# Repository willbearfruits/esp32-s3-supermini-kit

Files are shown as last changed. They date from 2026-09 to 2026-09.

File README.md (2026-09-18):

# ESP32-S3 SuperMini Audio Kit

An open-source, solderless, 3D-printable handheld built around the ESP32-S3
SuperMini. Microphone in, stereo line-out, a small OLED, an encoder,
a joystick, and optional speaker amplification, distance sensing and an IMU.
Headphones require a separate headphone amplifier.

This repo will grow into everything needed to build one or sell one: firmware,
carrier PCB, enclosure, bill of materials, and assembly instructions.

**Status: five firmware applications, a printable case, a purchasing list, and
an illustrated prototype assembly guide.** The carrier PCB remains unfinished;
the current build uses prepared headers and a wired harness.

## Build your first kit

[**Start the beginner-friendly assembly guide**](docs/assembly/README.md) ·
[**Printable PDF (16 pages)**](output/pdf/esp32-s3-supermini-assembly-guide.pdf) ·
[Browser checklist](docs/assembly/index.html) ·
[SVG and PNG diagrams](docs/assembly/assets/)

Make a little noise: the SuperMini handheld

Build it one small win at a time: flash the test app, light the screen, add the
mic and line-out, check the controls, fit the case, and make your first beat.
The guide includes wiring tables, checkpoints, case hardware, and troubleshooting.
Download the repository and open `docs/assembly/index.html` for the offline
interactive checklist. Exact module revisions and enclosure fit need checking
before assembly; the guide documents the prototype, not a physically validated kit.

## Firmware applications

The firmware builds as one of:

| App | `tools/app.sh` | What it is |
|-----|---|---|
| JAM | `jam` (default) | Step sequencer and sampler for the boxed unit: six channels on a scale-locked grid, slices you can scratch, roll and chaos for breakcore, mixer with insert effects, eight pattern banks, a song page, autosave. Encoder and joystick only. |
| Looper | `looper` | Hum, beatbox or whistle and get a track: up to 8 tracks on a fixed grid, scenes and an arrangement, stereo mix, autosave, WAV/MIDI export over a USB drive mode. |
| Faust showcase | `faust` | Mic through seven [Faust](https://faust.grame.fr) programs (zita reverb, pitch shift, wah, amp sim, flanger, compressor, a pitch-following synth), each with presets. |
| Hardware test | `test` | Mic to DAC with a wiring diagnosis on the screen and serial log, a boot-time test tone, delay/reverb/beat repeat. Flash this first on a new build. |
| Instrument | `instrument` | The older eight-mode voice instrument. |

## Parts

| Part | Role | Bus |
|---|---|-----|
| ESP32-S3 SuperMini | brain, native USB | |
| INMP441 | MEMS microphone | I2S (RX) |
| PCM5102A | line-out DAC (headphones need an amp) | I2S (TX) |
| MAX98357A | 3 W speaker amp | I2S (TX) |
| 0.96" SSD1306 OLED | display | I2C |
| Rotary encoder with button | input | GPIO |
| Analog joystick with button | input | ADC1 + GPIO |
| VL53L0X (optional) | time-of-flight distance | I2C |
| MPU6050 (optional) | gyro + accelerometer | I2C |

All three audio chips share one I2S port. See [docs/pinmap.md](docs/pinmap.md)
for the wiring and why that works.

The current [minimal purchasing list](parts/minimal-kit.md) is **your carrier PCB
plus seven parts**: ESP32-S3, purple PCM5102A board, joystick board with pins,
bare encoder, round six-pin I2S mic, 0.96-inch I2C OLED and MPU6050 board.
Available as [PDF](parts/minimal-kit.pdf) and [CSV](parts/minimal-kit.csv).
The [earlier expanded research](parts/purchasing-kit.md) keeps the additional
options and CAD references. Shipping and exact module dimensions remain unverified.

## Repo layout

```
firmware/     ESP-IDF project (C, a little C++ for the Faust glue)
firmware/faust/  Faust sources; tools/faustgen.sh turns them into C++ under firmware/main/faust/
tools/        app.sh (switch application), faustgen.sh
docs/         pin map, wiring diagram, acoustics notes
enclosure/    parametric OpenSCAD case, renders and STLs (0.8 mm nozzle, heat-set inserts)
3d/           earlier concept bodies (slab, ocarina, cup)
parts/        purchasing lists, datasheets and drawings
images/       photos and rendered screens
hardware/     later: KiCad carrier PCB
```

## Build one

The illustrated [assembly guide](docs/assembly/README.md), also as a
[16-page PDF](output/pdf/esp32-s3-supermini-assembly-guide.pdf), takes a first-time
builder from parts to a first beat: power, flashing the test image, adding
one module at a time, the bench check, the case, then JAM.

## Flash a release

No toolchain needed: each [release](https://github.com/willbearfruits/esp32-s3-supermini-kit/releases)
has one `.bin` per application that flashes at offset 0 with esptool or in the
browser. See [docs/flashing.md](docs/flashing.md).

## Build the firmware

Requires [ESP-IDF](https://docs.espressif.com/projects/esp-idf/en/stable/esp32s3/get-started/index.html)
v5.5 or newer with the `esp32s3` target installed.

```sh
. ~/esp/esp-idf/export.sh        # or wherever your IDF lives
cd firmware
idf.py set-target esp32s3
idf.py build
idf.py flash monitor
```

The SuperMini's USB-C is wired to the S3's native USB, so it usually flashes
without pressing anything. If it does not show up, hold BOOT, tap RESET,
release BOOT, then flash again.

Pick the application with `tools/app.sh jam` (or `looper`, `faust`, `test`,
`instrument`), which edits `sdkconfig` and rebuilds. Tunables live under
`idf.py menuconfig` -> `Kit firmware`: application, mic gain, sample rate,
tempo, encoder steps, OLED rotation, whether the speaker amp is always on.

Wiring note: the INMP441's L/R pin may go to GND or VDD, the firmware finds
which I2S slot carries the mic. The joystick's VRy goes to GPIO1 and VRx to
GPIO2 (see [docs/pinmap.md](docs/pinmap.md)).

## Using JAM

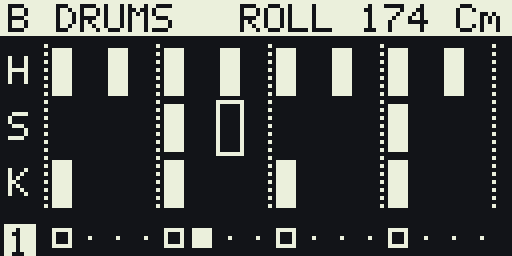
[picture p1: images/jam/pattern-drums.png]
drums
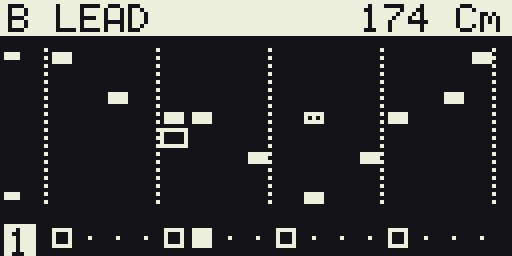
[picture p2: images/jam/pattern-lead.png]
lead
 
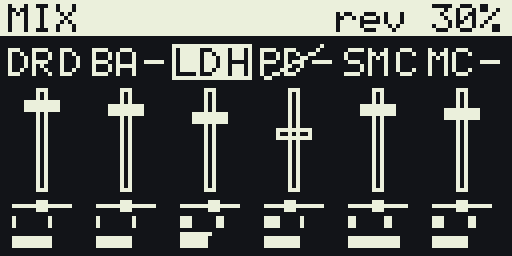
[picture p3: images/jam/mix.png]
mixer
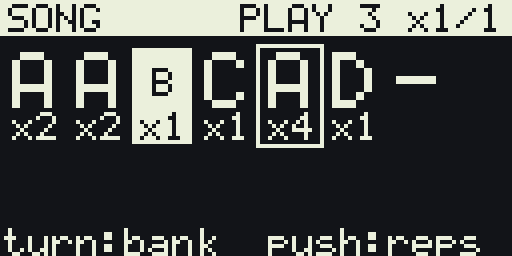
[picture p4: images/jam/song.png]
song
 

Four pages, cycled by holding the encoder for half a second: **PATTERN**,
**MIX**, **SONG**, **SETUP**. Push the encoder in and turn it to change
channel (DRUMS, BASS, LEAD, PAD, SAMPLE, MIC). Hold it 3 s to clear the
channel.

**PATTERN** is the step grid of the channel, two bars of 16 steps. Turn the
encoder or flick the joystick to move the cursor, tap the encoder to toggle
the cell. Drums have kick, snare and hat lanes. Melodic channels have one
row per degree of the scale chosen in SETUP plus the octave, so notes cannot
leave the key. PAD rows are chord degrees. SAMPLE plays the recording pitched
by row, or in SLICE mode one of eight slices per row, where a lit cell tapped
again plays in reverse. MIC is the live mic, only audible while selected;
tap the encoder there to record up to two seconds into the sampler.

Click the joystick for **perform** mode. On DRUMS the stick rolls the last
hit, from 1/8 to 1/64 by tilt, louder or softer along the other axis. On
SAMPLE it first scratches the recording like a record, click again and it
rolls with a pitch ramp. On BASS and LEAD it opens the filter and bends, on
PAD and MIC it pushes the reverb and delay sends. Hold the encoder and flick
up or down to switch pattern bank, A to H, instantly.

**MIX** shows a fader per channel with pan, reverb and delay sends, an insert
effect (drive, crush, chorus, phaser, wobble, tremolo) and its amount.
**SONG** chains banks with repeat counts, tap to play from the cursor.
**SETUP** has tempo up to 250, root and scale (major, minor, dorian,
mixolydian, harmonic minor, two pentatonics, blues), a drum pattern to load
into the grid, swing, CHAOS (the chance that a step rolls, drops, swaps or
reverses), the drum kit and synth presets, and COPY and CLEAR ALL.

Everything is saved two seconds after the last edit and comes back at
power-up.

## Using the looper

One encoder, one joystick, optional tilt sensor and distance sensor. Same
grammar everywhere:

| Gesture | Does |
|---|---|
| turn | next / previous track (in the menu: move, or change a value) |
| push | record a take on this track; push again to cancel |
| hold 0.6 s | menu (in the menu: back) |
| hold 3 s | clear all patterns |
| joystick tilt | expression: brightness and pitch bend |
| joystick click | mute this track |
| joystick flick up / down | next / previous scene, switched at the loop start |
| joystick flick left / right | track |
| body tilt | vibrato (roll) and brightness (pitch) |
| hand over the distance sensor | space (reverb send) |

A take is exactly one loop. Push, the metronome counts in one bar (or waits
for the loop to come round once something is playing), the take records for
one loop and stops by itself. Takes overdub by default; Take -> Replace next
or Undo change that. Drums are beatboxed (kick / snare / hat by the sound's
band energies), bass, keys and lead are hummed or whistled and snapped to
the grid and the key, the vocal track is a hard-tuned voice recorded as
audio. The key locks on the first melodic take, or set it in Song -> Key.

Menu sections: **Take** (undo, replace, copy A here, clear), **Track**
(sound, volume, pan, reverb, delay, low cut, tone, mute, solo, add / delete
track), **Scene** (scene, song mode, arrangement), **Song** (tempo, bars,
key, count-in, metronome, quantise, swing, humanise, kit, mic gain, gate),
**Master** (pump, drive, tone), **Files** (export, save / load slot, new,
USB drive).

USB drive mode (Files -> USB drive, or hold the encoder at power-up) shows
the storage partition to the PC and makes the board a MIDI device. Drop
`kick.wav`, `snare.wav`, `hat.wav` into `kits/user/` for your own drum kit;
exports land in `export/` as one WAV per track, a stereo `mix.wav`,
`song.mid` and `song.txt`. Hold the button to return. Flashing needs the
board out of USB mode (or BOOT held at power-up).

The serial log prints the current track, scene, key, the voice tracker's
level and confidence, the DSP load with a per-section breakdown, and which
inputs were detected.

## Faust

Effects and the JAM synth voice are written in Faust under `firmware/faust/`.
After editing a `.dsp`, run `tools/faustgen.sh` (needs the `faust` compiler
on PATH) to regenerate the C++ classes under `firmware/main/faust/`, which
are committed so a normal build never needs Faust. Avoid table-based
oscillators on this chip, each costs 256 KB of internal RAM.

## Roadmap

- [x] Pin map
- [x] I2S loopback (mic -> DACs)
- [x] OLED, encoder and joystick input
- [x] ToF and IMU readouts (looper)
- [x] 3D-printed enclosure ([enclosure/](enclosure/), first revision)
- [x] Purchasing list ([parts/minimal-kit.md](parts/minimal-kit.md))
- [ ] Carrier PCB (KiCad) with sockets for every module
- [x] Illustrated prototype assembly guide ([web](docs/assembly/README.md), [PDF](output/pdf/esp32-s3-supermini-assembly-guide.pdf), SVG/PNG artwork)

## License

Firmware and documentation: [MIT](LICENSE). Hardware files, when they land,
will be CERN-OHL-P.

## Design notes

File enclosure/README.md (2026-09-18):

# 3D OpenSCAD Enclosure for ESP32-S3 Audio Kit (Shortlist Edition)

For the full build, use the [beginner assembly guide](../docs/assembly/README.md)
or [16-page printable PDF](../output/pdf/esp32-s3-supermini-assembly-guide.pdf).
It covers bench testing, wiring, dry-fit checks, and enclosure assembly. The
dimensions below describe the CAD; verify them against your actual boards,
headers, plugs, inserts, and screws before printing or fastening.

A custom, ergonomic, 3D-printable handheld enclosure designed specifically for the **six parts of the Minimal Audio Kit shortlist** (plus internal mounting for the MPU6050 IMU), optimized for **0.8 mm nozzle printing** and **brass heat-set threaded inserts**.

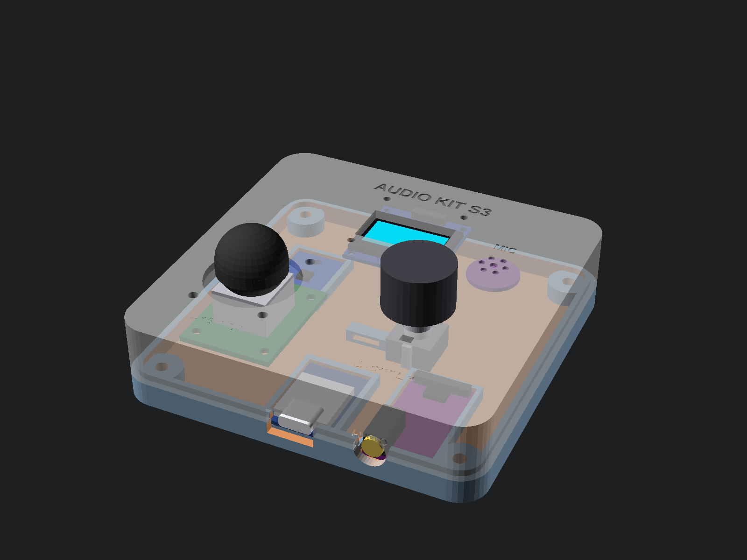
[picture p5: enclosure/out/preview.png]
Enclosure Preview


---

## 1. Overall Dimensions & Specifications

- **Outer Dimensions:** `100.0 mm` (Width, X) × `98.0 mm` (Length, Y) × `24.0 mm` (Height, Z)
- **Top Shell Height:** `17.0 mm`
- **Bottom Lid Height:** `7.0 mm` (parting line at Z = 7.0 mm)
- **Corner Radius:** `8.0 mm` rounded ergonomic corners
- **Wall Thickness:** `2.4 mm` (exactly 3 perimeters of 0.8 mm nozzle extrusion)
- **Floor & Ceiling Thickness:** `2.4 mm` (solid 6 layers at 0.40 mm)

---

## 2. The Six Shortlist Parts & Placement

| # | Part | Role & Specification | Enclosure Integration |
|---|---|---|---|
| **1** | **ESP32-S3 SuperMini** | ESP32-S3FH4R2, 4MB Flash / 2MB PSRAM, USB-C | Lower-center lid cradle (`X = 41.0 to 59.0 mm`); USB-C port cutout on bottom edge with cable shroud relief. |
| **2** | **PCM5102A I2S DAC** | **32 × 17 mm** purple board, 3.5mm jack on a short end, offset to one side. Size, jack edge, jack offset and which wall it exits are in the Customizer group *PCM5102A DAC board* in `enclosure.scad`. | Lid cradle along the right wall (`X = 68.5 to 85.5 mm`, `Y = 2.9 to 34.9 mm`), jack **exits through the front wall** beside the USB-C port. |
| **3** | **Analog Joystick** | KY-023-style module with fitted pins and thumb cap | Lower-left quadrant (`X = 22.5, Y = 32.5 mm`); 26.5 mm diameter dome aperture; 4 M2 internal screw bosses with **>3.7 mm clearance to ESP32 cradle** and **>5.2 mm to ESP32 PCB** (zero overlap). |
| **4** | **Rotary Encoder** | Bare EC11 with push switch and vertical shaft | Lower-right quadrant (`X = 70.0, Y = 32.5 mm`); 7.5 mm through-hole for M7 threaded bushing, anti-rotation locator notch, recessed dial bezel. |
| **5** | **I2S Microphone** | **Round 14.5 mm 6-pin board** (INMP441) | **Mounted on top layer next to the OLED display** (`X = 78.0, Y = 65.0 mm`); acoustic 7-hole rosette grille with conical chamfers, internal gasket seat, and circular retention collar (zero overlap with OLED). |
| **6** | **0.96-inch OLED** | SSD1306, 128×64, 4-pin I2C | Upper front center (`X = 36.35 to 63.65 mm, Y = 58.0 mm`); recessed beveled viewing window; 4 M2 mounting standoffs. |
| *(7)* | *MPU6050 IMU* | *GY-521 6-DoF accelerometer & gyro (motion sensor)* | *Internal retention cradle on lid floor; rigidly anchored to chassis for tilt sensing.* |

---

## 3. 0.8 mm Nozzle & Heat-Set Insert Engineering

### A. 0.8 mm Nozzle Geometries
Printing with a 0.8 mm nozzle requires walls, perimeters, and tolerances to be integer multiples of the extrusion line width:
- **Wall Thickness:** `2.4 mm` (exactly 3 solid perimeters of 0.8 mm).
- **Floor & Roof Thickness:** `2.4 mm` (6 solid layers at 0.40 mm layer height).
- **Alignment Lip (Tongue & Groove):** `1.6 mm` (exactly 2 solid perimeters).
- **Sliding Clearance (`tol`):** `0.40 mm` (accommodates 0.8 mm corner bulging for a smooth sliding fit).
- **Acoustic Grille Openings:** 7-hole rosette (center: 2.2 mm, surround: 1.8 mm) allows the 0.8 mm nozzle to lay down crisp circular paths without stringing or merging.
- **Labels:** Bold embossed/debossed typography with stroke widths exceeding 0.8 mm for clean legibility.

### B. Heavy-Duty Brass Heat-Set Threaded Inserts
Rather than self-tapping into weak plastic, the top shell contains thick, heavy-duty structural corner bosses designed for **heat-set brass threaded inserts**:
- **Default configuration:** `insert_type = "M3"`:
  - **Boss Outer Diameter:** `Ø11.5 mm` (providing **~3.5 mm solid wall thickness / ~4.5 continuous perimeters** around the brass insert).
  - **Insert Hole Diameter:** `Ø4.5 mm` (tailored for standard M3 heat-set inserts with OD ~4.6 mm).
  - **Insert Depth:** `5.8 mm` (for standard 4.0 mm – 5.7 mm insert lengths).
  - **Conical Lead-In Chamfer:** 0.8 mm deep 45° lead-in chamfer ensures the brass insert rests perfectly vertical and self-centers before touching with the soldering iron tip.
- **Selectable in OpenSCAD:** Supports `"M2"`, `"M2.5"`, or `"M3"` with matching screw clearances and counterbores.
- **Lid Screw Holes:** `Ø3.6 mm` pass-through clearance with `Ø7.2 mm × 3.2 mm` deep counterbores so M3 socket/pan head screws sit flush with the bottom surface.

---

## 4. Exploded Assembly

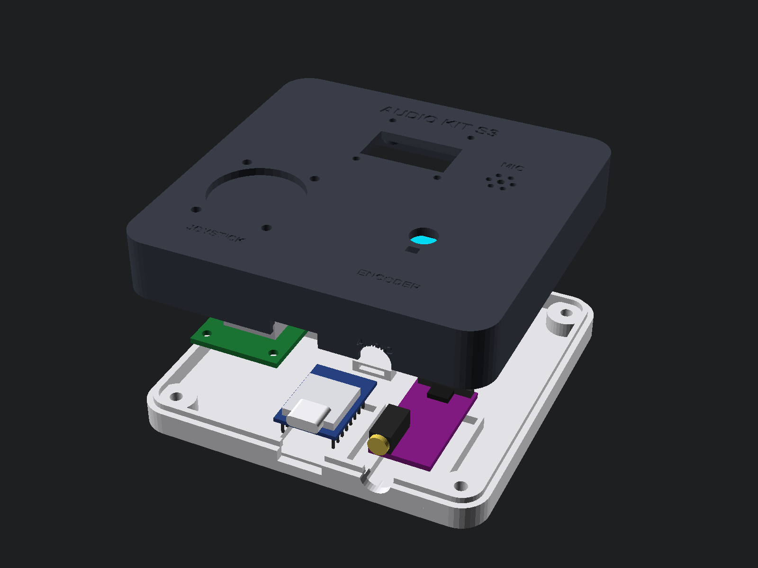
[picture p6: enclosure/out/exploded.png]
Exploded Assembly


1. **Top Shell Prep & Assembly:**
   - Press four **M3 brass heat-set inserts** into the corner bosses using a soldering iron (set to ~230–250°C for PLA/PETG).
   - Fasten the **SSD1306 OLED** to the upper window bosses with four M2 screws.
   - Place a small foam/silicone gasket ring into the microphone seat on the top layer, press the **Round INMP441 mic** into its circular collar, and route leads.
   - Insert the **EC11 Encoder** through its panel hole and tighten the M7 nut on the outside; press the knob onto the 6mm D-shaft.
   - Mount the **KY-023 Joystick** onto its four standoff bosses using four M2 screws.
2. **Bottom Lid Assembly:**
   - Slide the **ESP32-S3 SuperMini** into its cradle (USB-C facing outward on the bottom edge).
   - Slide the **PCM5102A DAC** into its cradle (3.5mm stereo jack facing outward through the front wall cutout beside the USB-C).
   - Press the **MPU6050 IMU** into its internal retention cradle.
   - Wire connections according to [`docs/pinmap.md`](../docs/pinmap.md) and secure wires through the cable anchor loop.
3. **Closing Case:**
   - Place the bottom lid onto the top shell (the 1.6 mm interlocking lip aligns both halves smoothly).
   - Fasten with four **M3 × 10 mm (or 12 mm)** socket-head or pan-head machine screws from the underside (counterbored flush).

---

## 5. 3D Printing Guidelines

Both parts are designed for **100% support-free printing**:

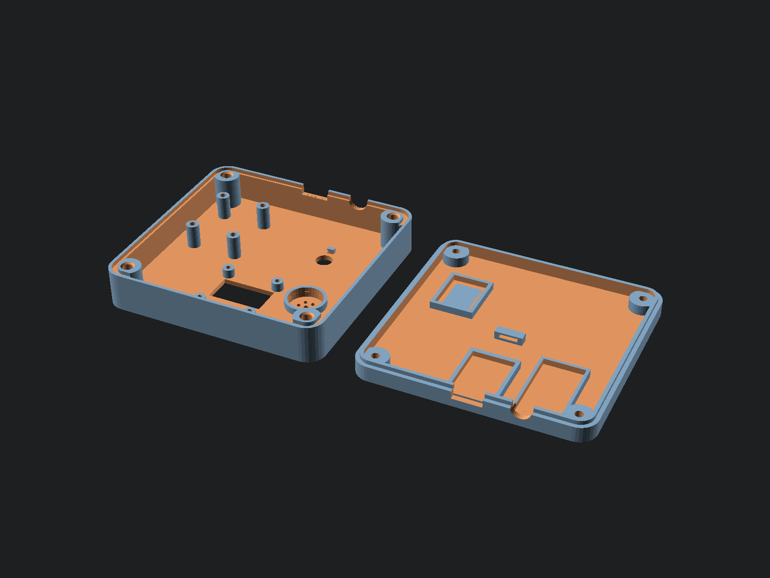
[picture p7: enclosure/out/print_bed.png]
Print Bed Layout


- **Print Bed Setup:** Open [`print_bed.scad`](print_bed.scad) or load [`out/print_bed.stl`](out/print_bed.stl) directly into your slicer (OrcaSlicer, PrusaSlicer, Bambu Studio, Cura).
- **Top Shell Orientation:** Printed **top-face down** flat on the build plate (Z=0). Heat-set insert bosses and walls grow vertically upward.
- **Bottom Lid Orientation:** Printed **bottom-face down** flat on the build plate (Z=0).
- **Nozzle Diameter:** 0.8 mm
- **Recommended Material:** PLA, PLA+, or PETG.
- **Layer Height:** 0.32 mm – 0.40 mm (fast printing, ~1 hour total print time!).
- **Perimeters / Walls:** 3 perimeters (gives 100% solid 2.4 mm walls).
- **Top / Bottom Solid Layers:** 4 to 6 layers.
- **Infill:** 20% to 30% (Gyroid or Grid).
- **Supports:** **NONE** (0% support needed).

---

## 6. Hardware Bill of Materials

| Item | Quantity | Purpose |
|---|---|---|
| M3 brass heat-set inserts (OD ~4.6 mm, L ~4–5.7 mm) | 4 | Corner fasteners in Top Shell (or M2.5 / M2) |
| M3 × 10 mm (or 12 mm) machine screws | 4 | Case closure through Bottom Lid (counterbored flush) |
| M2 × 4 mm screws | 4 | OLED display mounting |
| M2 × 6 mm screws | 4 | KY-023 Joystick module mounting |
| EC11 M7 nut & washer | 1 | Rotary encoder panel fixing |
| Foam/silicone gasket ring (~10–14 mm OD) | 1 | Microphone acoustic isolation |
| Rubber bumper feet (~8 mm diameter) | 4 | Optional non-slip feet for lid recesses |

---

## 7. Files & Customization

- [`enclosure.scad`](enclosure.scad): Main parametric OpenSCAD design script.
- [`parts.scad`](parts.scad): 3D component models and negative cutouts library.
- [`print_bed.scad`](print_bed.scad): Build plate layout file for single-plate slicing.
- [`render.sh`](render.sh): Shell script to render PNG previews and export STLs.
- [`out/`](out/):
  - [`print_bed.stl`](out/print_bed.stl): Ready-to-slice 2-in-1 build plate STL (Top Shell + Bottom Lid).
  - [`shell.stl`](out/shell.stl): Ready-to-slice Top Shell STL.
  - [`lid.stl`](out/lid.stl): Ready-to-slice Bottom Lid STL.
  - `preview.png`: Transparent assembled preview.
  - `exploded.png`: Exploded assembly diagram.
  - `assembled.png`: Solid external case view.
  - `print_bed.png`: Both parts arranged flat for 3D printing.

### CLI Rendering Commands

```bash
# Render all views and STLs
./render.sh

# Or open interactively in OpenSCAD
openscad enclosure.scad
```

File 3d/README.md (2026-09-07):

# 3D-printable bodies

Parametric OpenSCAD (tested with 2021.01). Three options that share one
parts library:

| File | Option | Idea |
|---|---|---|
| `handheld.scad` | A, slab | Game-Boy-shaped box: OLED, encoder, joystick on top, sealed speaker sub-box, mic on the top edge, battery under the lid. |
| `ocarina.scad` | B, ocarina | A Helmholtz chamber sized for a chosen lowest note, fipple and four finger holes; the mic listens inside the chamber. Electronics in a bay underneath. |
| `cup.scad` | C, cup on a wand | Mic at the bottom of a cup you press to your mouth, controls along the handle. Maximum isolation for beatboxing. |

`parts.scad` holds every module's size. **All of them are typical values,
not measurements.** Measure your boards and fix the numbers before printing.
`acoustics.scad` has the resonance formulas, explained in
[docs/acoustics.md](../docs/acoustics.md).

```sh
./render.sh            # previews in out/*.png and STLs in out/*.stl
openscad handheld.scad # or open interactively
```

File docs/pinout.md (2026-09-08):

# Pinout

| Pin | Function | Goes to | Notes |
|----:|---|---|---|
| | | | |

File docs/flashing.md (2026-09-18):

# Flashing without ESP-IDF

Every [release](https://github.com/willbearfruits/esp32-s3-supermini-kit/releases)
ships one image per application, each a single file that flashes at offset 0:

| File | Application |
|---|---|
| `kit-jam.bin` | JAM, the step sequencer and sampler (what the boxed kit runs) |
| `kit-looper.bin` | the voice looper |
| `kit-test.bin` | hardware test: mic to DAC with a wiring diagnosis on the screen |

## With esptool (Linux, macOS, Windows)

```sh
pip install esptool
esptool.py --chip esp32s3 --port /dev/ttyACM0 write_flash 0x0 kit-jam.bin
```

Use the port your system gives the board: `/dev/ttyACM0` on Linux,
`/dev/cu.usbmodem*` on macOS, `COM3` or similar on Windows. Leave `--port`
out and esptool tries them all.

## In the browser

Open [esptool-js](https://espressif.github.io/esptool-js/) in Chrome or Edge,
connect, choose the file with flash address `0x0`, program. No install.

## If the board does not show up

The SuperMini uses the S3's native USB, so it normally enumerates by itself.
If it does not, or the flash fails partway: hold BOOT, tap RESET, release
BOOT, then flash again. The board reboots into the new firmware afterwards.
A cable that only carries power is the usual cause of a board that never
appears.

## After flashing

JAM saves its patterns on the board; a first boot writes defaults. The
hardware test image is the one to flash when something is wired wrong: it
names the likely missing wire on the screen and in the serial log at
115200 baud.

## Building the images yourself

`tools/release.sh` with ESP-IDF sourced builds all three and merges each with
its bootloader and partition table into `release/<version>/`.

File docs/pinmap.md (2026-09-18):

# Pin map

Board: **ESP32-S3 SuperMini** (ESP32-S3FH4R2, 4 MB flash, 2 MB PSRAM, native USB).
All GPIO logic is 3.3 V. Module supply voltages differ: the documented
regulator-equipped purple DAC uses 5 V at VIN, while the microphone and
joystick use 3V3. Verify each breakout's supply rating and power path; the
optional speaker amp needs a supply with enough current, not an assumed load
on the SuperMini's small 3V3 regulator.

New to the build? Follow the [illustrated assembly guide](assembly/README.md)
or its [printable PDF](../output/pdf/esp32-s3-supermini-assembly-guide.pdf).
Its staged diagrams use signal labels, not physical header positions.

The canonical copy of this table lives in `firmware/main/pins.h`. If you change one, change the other.

| GPIO | Name | Goes to | Notes |
| -: | - | - | - |
| 1 | JOY\_Y | Joystick VRy | ADC1 |
| 2 | JOY\_X | Joystick VRx | ADC1 |
| 3 | JOY\_SW | Joystick SW | active low, internal pull-up |
| 4 | ENC\_A | Encoder CLK / A |  |
| 5 | ENC\_B | Encoder DT / B |  |
| 6 | ENC\_SW | Encoder SW | active low, internal pull-up |
| 7 | I2S\_BCLK | INMP441 **SCK**, PCM5102A **BCK**, MAX98357A **BCLK** | shared bit clock |
| 8 | I2S\_WS | INMP441 **WS**, PCM5102A **LCK**, MAX98357A **LRC** | shared word select |
| 9 | I2S\_DOUT | PCM5102A **DIN**, MAX98357A **DIN** | ESP32 -\> DACs |
| 10 | I2S\_DIN | INMP441 **SD** | mic -\> ESP32 |
| 11 | AMP\_SD | MAX98357A **SD** | low = amp off |
| 12 | I2C\_SDA | OLED, ToF, IMU SDA |  |
| 13 | I2C\_SCL | OLED, ToF, IMU SCL |  |
| 21 | SPARE | free | ToF XSHUT or IMU INT later |

Pins deliberately left alone: 0 (BOOT button), 19/20 (USB), 43/44 (UART0), 48 (onboard RGB LED), 45/46 (strapping).

Why the joystick sits on GPIO1 and GPIO2: those are ADC1 channels. ADC2 stops working while WiFi is active on the ESP32-S3, so never put analog inputs there.

## Why one I2S port is enough

The ESP32-S3 has two I2S ports. We use only port 0, in full duplex:

- The two DACs are receivers. Receivers can share a bus freely, so both get the same BCLK, WS and data line and play the same stream.

- The mic is a transmitter, so it needs its own data line into the ESP32, but it can still share BCLK and WS with the DACs.

- The only rule is that everyone runs at the same sample rate and slot width. We use 32-bit slots, stereo, Philips format. All three chips accept that.

- None of the three chips needs MCLK.

Total cost: 4 GPIOs for the entire audio path.

Trade-off: both DACs always play the same audio. If you ever want different audio on speaker vs line-out, move one DAC to I2S port 1 (3 more pins).

## Module wiring

### INMP441 microphone (round board, 6 pins)

| INMP441 | Connect to |
| - | - |
| VDD | 3V3 |
| GND | GND |
| SD | GPIO 10 |
| SCK | GPIO 7 |
| WS | GPIO 8 |
| L/R | GND (data lands in the left slot; the firmware also accepts it tied to VDD, right slot) |

### PCM5102A DAC (purple board, line-out)

The output is line level. Use powered speakers, an audio-interface line input,
or a separate headphone amplifier; ordinary headphones need amplification.
Confirm the regulator, VIN rating, and strap functions for your exact board.

| PCM5102A | Connect to |
| - | - |
| VIN | 5V (the board has its own 3.3 V regulator; on 3V3 it sags to ~3.0 V and the analog side suffers) |
| GND | GND |
| LCK | GPIO 8 |
| DIN | GPIO 9 |
| BCK | GPIO 7 |
| SCK | GND (most boards already do this on the PCB) |

Check the four solder bridges on the back. They must be:

| Bridge | Pin | Set to |
| - | - | - |
| H1L | FLT | L |
| H2L | DEMP | L |
| H3L | XSMT | H |
| H4L | FMT | L |

Boards often ship with one or more of these open. An open XSMT means the DAC stays muted forever. This is the one component in the kit that may need a soldering iron, so for a solderless kit either buy pre-bridged boards or move these straps onto the carrier PCB.

### MAX98357A amplifier (speaker out)

| MAX98357A | Connect to |
| - | - |
| VIN | Verified regulated supply within the module's rating, with enough current for the speaker load; keep GPIO logic at 3.3 V |
| GND | GND |
| SD | GPIO 11 |
| GAIN | leave floating (9 dB) |
| DIN | GPIO 9 |
| BCLK | GPIO 7 |
| LRC | GPIO 8 |
| + / - | speaker, 4 or 8 ohm |

Driving SD low shuts the amp down; channel selection with SD high depends on
the breakout's SD_MODE network. The firmware starts with it low and, by default,
enables it while the GPIO6 encoder switch is held. `CONFIG_KIT_AMP_ALWAYS_ON`
keeps it enabled. Neither speaker output terminal may be connected to GND.
See the assembly guide's optional-extension section for power and mounting limits.

### I2C devices

All on GPIO 12 (SDA) and GPIO 13 (SCL). Addresses do not clash:

| Device | Address |
| - | - |
| SSD1306 0.96" OLED | 0x3C |
| VL53L0X ToF (the current driver does not implement VL53L1X) | 0x29 |
| MPU6050 IMU | 0x68 |

Most breakout boards include pull-ups. If none of yours do, add 4.7 k to 3V3 on SDA and SCL.

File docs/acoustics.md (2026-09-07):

# Acoustics for the enclosure

What the box can and cannot do for a MEMS microphone, with the formulas the
OpenSCAD files use. Speed of sound c = 343 m/s.

## The one formula that matters: Helmholtz

A cavity of volume V with an opening of area A and neck length L resonates at

    f = c / (2 pi) * sqrt( A / (V * L_eff) ),   L_eff = L + 1.7 r

where r is the opening radius and the 1.7 r term is the end correction. This
is the ocarina, the cup, a ported speaker box and a bottle, all at once.

Turned around: the volume you need for a target frequency is

    V = A / ( L_eff * (2 pi f / c)^2 )

### Consequence 1: no handheld cavity reaches kick range

For 100 Hz with a 20 mm opening and a 20 mm neck you need 2.5 litres. For
200 Hz still 630 cm3. Anything that fits in a hand (50-150 cm3) resonates
between 400 and 900 Hz, the vowel range. So the enclosure cannot boost the
"b" of a beatbox kick. Kick versus hat separation stays electronic, which the
firmware already does with band energies.

### Consequence 2: it reaches whistle range easily

The same 81 cm3 chamber with a 4 x 12 mm window resonates at A4 = 440 Hz. That
is an ocarina, and it is the strongest acoustic idea for this kit: a fipple
turns breath into a loud, pure tone with a stable fundamental. The YIN
tracker locks onto it instantly, with none of the jitter a voice gives, and it
is 20 dB above room noise so the gate has nothing to think about. Voice and
beatbox still work on the other pages, the ocarina is just a very good pitch
controller for bass, chords and lead.

Finger holes add their own A / L_eff to the sum inside the square root, so
opening a hole raises the pitch. `ocarina.scad` solves the hole diameters for
a list of target notes; expect to be within a semitone and then tune by
enlarging (sharper) or taping (flatter), as every ocarina maker does.

## Tubes

A tube closed at one end resonates at odd multiples of c / 4L. A 15 cm tube
gives 572, 1715, 2858 Hz: a talkbox-like colour on the voice, nothing at the
fundamental. Fun, but it does not help tracking.

## What a cup does

The INMP441 is omnidirectional, so it has no proximity effect: there is no
bass boost from getting close. What a cup around the mic gives is isolation.
Lips on the rim, the voice arrives at the mic 15-20 dB above the room and the
speaker, which is exactly the "mic is too sensitive" complaint solved in
plastic. Sealed by the lips it becomes a Helmholtz resonator around 700 Hz
(printed by `cup.scad`), mild vowel colour, harmless for pitch.

## The microphone port

The INMP441 hears through a hole in its PCB. Mount the board face-down over a
1.5 mm port in the shell with a thin foam or rubber gasket so sound only
enters through the port. Keep the port short: a long narrow port plus the
tiny cavity in front of the membrane makes its own resonance, and below about
2 mm length and 1.5 mm diameter that sits above 10 kHz where it does not
matter. A slotted grille 5 mm in front of the port, with a thin foam disc,
is the pop filter.

## The speaker

A 40 mm 3 W driver in a sealed box needs volume to keep any bass: 26 cm3 (the
slab as drawn) is on the small side, 60-100 cm3 is comfortable. A port would
have to be large to tune below 200 Hz (see consequence 1), so stay sealed and
let the firmware make the bass. What matters more is feedback: the speaker
box must be its own sealed volume, separate from the mic side, with foam in
between, or the mic-to-speaker loop howls with the amp on.

## Gyroscope

Not acoustic, but worth deciding now: the MPU6050 goes near the centre of the
body, screwed rigidly to the shell, axes aligned with the body. Tilt then
maps cleanly to expression (vibrato, filter, pitch bend) without calibration
tricks.

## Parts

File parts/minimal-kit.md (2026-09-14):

# Minimal audio kit — 7 parts

**Your carrier PCB + seven purchased parts per kit.** For ten kits: buy ten of each, preferably one 10-piece lot. Scope confirmed 9 September 2026: **joystick on a board with pins; encoder bare**.

| # | Part | Required version | AliExpress candidate |
|---|---|---|---|
| 1 | ESP32-S3 SuperMini | ESP32-S3FH4R2, 4 MB flash / 2 MB PSRAM, USB-C | [1–10 pcs](https://www.aliexpress.com/item/1005012191736844.html) |
| 2 | PCM5102A I2S DAC | **Purple board**, with audio jack | [1–10 pcs](https://www.aliexpress.com/item/1005010369195534.html) |
| 3 | Analog joystick | **KY-023-style board with fitted pins and cap**; X, Y and push button | [1/5/10 pcs](https://www.aliexpress.com/item/1005008298413198.html) |
| 4 | Rotary encoder | **Bare EC11 with push button**, vertical shaft | [10 pcs](https://www.aliexpress.com/item/1005005239756119.html) |
| 5 | I2S microphone | **Small round six-pin board**; INMP441 assumed from this project | [1/5/10 pcs](https://www.aliexpress.com/item/1005009006830769.html) |
| 6 | 0.96-inch OLED | SSD1306, 128×64, **I2C SDA/SCL**, four pins | [10 pcs](https://www.aliexpress.com/item/1005008169257099.html) |
| 7 | Gyroscope / accelerometer | **MPU6050 GY-521 board**, I2C | [10 pcs](https://www.aliexpress.com/item/1005011896641210.html) |

**Ordering status:** these are listing leads. Select the 10-piece variant where available. Free shipping/Choice, fitted headers, the purple DAC version, round microphone version and exact board drawings remain **unverified**. Country/postcode and readable seller details are still needed. The ten-kit batch is **70 purchased parts + 10 of your carrier PCBs**.

**Documentation and CAD:** [PCM5102A datasheet](https://www.ti.com/lit/ds/symlink/pcm5102a.pdf) · [INMP441 datasheet](https://invensense.tdk.com/wp-content/uploads/2015/02/INMP441.pdf) · [MPU6050 datasheet](https://product.tdk.com/system/files/dam/doc/product/sensor/mortion-inertial/imu/data_sheet/mpu-6000-datasheet1.pdf) · [KY-023 module manual/dimensions reference](https://www.joy-it.net/en/products/COM-KY023JM) · [SSD1306 OLED module dimensions reference](https://www.joy-it.net/files/files/Produkte/SBC-OLED01/SBC-OLED01_Datasheet_2022-01-06.pdf). Reference-board dimensions must be matched to the actual supplier's boards. Exact DipTrace libraries remain unverified; existing drawings and CAD leads are in the [detailed research](purchasing-kit.md).

**Carrier design:** use the actual module header layouts and bare encoder footprint. Keep joystick outputs and I2C pull-ups at 3.3 V. The purple DAC's input power and configuration straps depend on its revision. Its output is line level; if headphone drive is wanted, account for that in the carrier design. [TI DAC specification](https://www.ti.com/lit/ds/symlink/pcm5102a.pdf).

Listing-title evidence: [ESP32](https://sv.pricearchive.org/aliexpress.com/item/1005012191736844) · [DAC](https://www.pricearchive.org/aliexpress.com/item/1005010369195534) · [joystick](https://ms.pricearchive.org/aliexpress.com/item/1005008298413198) · [encoder](https://sv.pricearchive.org/aliexpress.com/item/1005005239756119) · [mic](https://vi.pricearchive.org/aliexpress.com/item/1005009006830769) · [OLED](https://ro.pricearchive.org/aliexpress.com/item/1005008169257099) · [IMU](https://www.pricearchive.org/aliexpress.com/item/1005011896641210). These indexed records do not verify shipping or the selected variant.

[Editable seven-part CSV](minimal-kit.csv) · [Earlier expanded research](purchasing-kit.md)

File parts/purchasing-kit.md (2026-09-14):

# ESP32-S3 audio kit — purchasing shortlist

**Earlier expanded research.** The current build uses [seven purchased parts plus your carrier PCB](minimal-kit.md), with a joystick board with pins and a bare encoder. Use that minimal list for the current kit; the broader options below are retained as research references.

Research date: **9 September 2026**. Working quantity: **10 complete kits**. Encoder and joystick are **bare through-hole components, without breakout boards**; the other electronics are modules. Destination and this quantity assumption await confirmation.

**Purchase status: shipping and exact-product drawing checks are pending. No listing is yet confirmed to meet all your requirements.** This document contains real listing leads, manufacturer documentation and the remaining parts needed to finish the build. It is not an AliExpress cart, and no orders have been placed.

AliExpress product pages could not be read successfully through the research tool. The listing links below were identified through indexed Pricearchive/Alitools records; their titles establish candidate parts and advertised pack sizes only. Stock, selected variants, seller identity, authenticity, Choice eligibility, prices and delivery charges remain unverified. The adjacent “listing evidence” links preserve that distinction.

## Your buying requirements

- Prefer one **10-piece lot** per part; larger lots are acceptable. A listing headed “1–10 pieces” needs the **10-piece variant**, with cart quantity **1**. Ten single pieces or five pairs are exceptions, not automatically equivalent to the requested lot.
- Require **zero shipping charge to your delivery address** for the selected lot. I interpret “AliExpress special” as **Choice**, pending confirmation. Alibaba describes Choice shipping as conditional on market and purchase thresholds; its general description does not establish today's terms for your address. Check both the product and final basket. [Alibaba's Choice explanation](https://www.alibabagroup.com/en-US/document-1696296090350911488).
- Require a manual/datasheet with **dimensions and mounting information for the actual item supplied**. For modules this means the PCB, header positions, holes, connector heights and protrusions. A chip's package drawing alone does not qualify a module.
- Prefer DipTrace symbols/footprints and matching STEP models. A similar-looking component or another manufacturer's breakout is only a reference.

## Main components: one of each per kit

Every row below has a target of **10 physical pieces**. Optional sensors are included in that target so all ten kits can have motion and distance control. **Shipping/Choice: unverified for every row. Live lot price: unverified for every row.**

| ID | Part and exact selection | Advertised lot and AliExpress link | Documentation / remaining gap |
|---|---|---|---|
| K01 | **ESP32-S3 SuperMini, ESP32-S3FH4R2**, 4 MB flash, 2 MB PSRAM, native USB-C | **1–10 pcs**, select 10: [listing](https://www.aliexpress.com/item/1005012191736844.html) · [listing evidence](https://sv.pricearchive.org/aliexpress.com/item/1005012191736844) | Exact SuperMini PCB drawing not verified. Firmware requires this S3/PSRAM configuration; a C3 SuperMini is unsuitable. Documented Waveshare alternative below. |
| K02 | **INMP441 I2S microphone breakout**, with L/R pin accessible | **1/5/10 pcs**, select 10: [listing](https://www.aliexpress.com/item/1005009006830769.html) · [listing evidence](https://vi.pricearchive.org/aliexpress.com/item/1005009006830769) | [TDK chip datasheet](https://invensense.tdk.com/wp-content/uploads/2015/02/INMP441.pdf). Exact board dimensions, acoustic-port position and pin layout still needed. Do not select a different microphone from a mixed listing without checking it. |
| K03 | **PCM5102A stereo I2S DAC module**, preferably with fitted 3.5 mm line-output jack | **1–10 pcs**, select 10: [listing](https://www.aliexpress.com/item/1005010369195534.html) · [listing evidence](https://www.pricearchive.org/aliexpress.com/item/1005010369195534) | [TI datasheet](https://www.ti.com/lit/ds/symlink/pcm5102a.pdf) · [saved PDF](research-2026-09-09/PCM5102A-chip-datasheet.pdf). Exact PCB/jack drawing, regulator and mute straps still needed. This is line output; see headphone amplifier below. |
| K04 | **MAX98357A mono I2S speaker amplifier module**; require the **A** version | **10 pcs / 1 pc**, select 10: [listing](https://www.aliexpress.com/item/1005009759175798.html) · [listing evidence](https://www.pricearchive.org/aliexpress.com/item/1005009759175798) | [Analog Devices datasheet/CAD](https://www.analog.com/en/products/MAX98357A.html). Listing title omits the suffix: confirm A, board dimensions, SD/GAIN circuitry and terminal block. A uses I2S; B uses left-justified audio. |
| K05 | **0.96-inch SSD1306 OLED**, 128×64, **4-pin I2C**, white | **10 pcs / lot**: [listing](https://www.aliexpress.com/item/1005008169257099.html) · [listing evidence](https://ro.pricearchive.org/aliexpress.com/item/1005008169257099) | Exact PCB, glass, active-area and mounting-hole drawing needed. Confirm 0x3C address, 3.3 V operation and header order. Do not substitute SH1106, 128×32 or SPI. |
| K06 | **Bare EC11 rotary encoder with push switch**, 3 encoder pins + 2 switch pins, vertical shaft | **10 pcs**, choose shaft style/length: [listing](https://www.aliexpress.com/item/1005005239756119.html) · [listing evidence](https://sv.pricearchive.org/aliexpress.com/item/1005005239756119) | **Hold for seller drawing.** Generic EC11 does not identify one footprint. Need body, lug spacing, shaft length/diameter, bushing, detents and pulses. Exact documented ALPS alternative below. No KY-040 board. |
| K07 | **Bare ALPS RKJXV1224005 joystick**, two 10 kΩ linear pots, spring return, center push | **10–100 pcs**, select 10: [listing](https://www.aliexpress.com/item/1005011995304794.html) · [listing evidence](https://ro.pricearchive.org/aliexpress.com/item/1005011995304794) | [ALPS exact-part documentation](https://tech.alpsalpine.com/e/products/detail/RKJXV1224005/). **17.8 × 21.3 × 11.2 mm**; dimension, mounting and lever drawings saved below. Best exact-model 10-piece lead found. Seller identity/authenticity and supplied model still need confirmation. Cap inclusion unknown. No KY-023 board. |
| K08 | **MPU6050 / GY-521 breakout**, gyro + accelerometer | **10 pcs**: [listing](https://www.aliexpress.com/item/1005011896641210.html) · [listing evidence](https://www.pricearchive.org/aliexpress.com/item/1005011896641210) | [TDK chip datasheet](https://product.tdk.com/system/files/dam/doc/product/sensor/mortion-inertial/imu/data_sheet/mpu-6000-datasheet1.pdf). Exact GY-521 PCB drawing needed. Require 3.3 V-compatible power/I2C and AD0 low for 0x68. Optional in firmware, included here. |
| K09 | **VL53L0X I2C distance-sensor breakout** | **10 pcs / 1 pc**, select specifically VL53L0X and 10: [listing](https://www.aliexpress.com/item/1005010777247203.html) · [listing evidence](https://uk.pricearchive.org/aliexpress.com/item/1005010777247203) | [ST datasheet](https://www.st.com/resource/en/datasheet/vl53l0x.pdf). Mixed-family listing: exact sensor, direct I2C interface, board drawing and voltage compatibility need confirmation. VL53L1X and serial-output TOF boards are not drop-in replacements for this firmware. Optional, included here. |
| K10 | **40 mm round speaker, 4 Ω, 3 W nominal**, with leads if possible | **1/2/10 pcs**, select 10 and 40 mm: [listing](https://www.aliexpress.com/item/1005009533204416.html) · [listing evidence](https://www.pricearchive.org/aliexpress.com/item/1005009533204416) | **Hold for full drawing.** Diameter alone is insufficient: magnet depth, rim, terminals and mounting are needed. The enclosure's 5.5 mm speaker depth is an unmeasured placeholder. |
| K11 | **Stereo headphone amplifier**, if headphones are required; TDA1308 board is a candidate | **10 pcs / 1 pc**, select 10: [listing](https://www.aliexpress.com/item/1005009791615188.html) · [listing evidence](https://ms.pricearchive.org/aliexpress.com/item/1005009791615188) | **Design/sourcing hold.** [NXP TDA1308 documentation](https://www.nxp.com/products/TDA1308). Require schematic, dimensions, stereo headphone load rating, gain and output coupling. Listing calls it a microphone preamp, so its suitability is unconfirmed. TDA1308 is discontinued; do not commit a new production design on this lead alone. |

No total cost is provided: indexed starting prices often correspond to one piece or a different variant. The CSV leaves actual selected-lot price and shipping fields blank for verified quotes.

## The bare controls and their drawings

**Joystick K07:** ALPS documents the exact RKJXV1224005, including its center switch. It is marked **not recommended for new designs**. For a longer-lived design, consider the current **RKJXV122400R**, documented as **18.2 × 21.7 × 11.2 mm**. The two outlines differ; do not use one drawing for the other. A matching 10-piece AliExpress lot for the R version was not confirmed. [4005 specifications](https://tech.alpsalpine.com/e/products/detail/RKJXV1224005/) · [400R specifications](https://tech.alpsalpine.com/e/products/detail/RKJXV122400R/).

| Saved manufacturer drawing | What it establishes |
|---|---|
| [RKJXV1224005 dimensions](research-2026-09-09/ALPS-RKJXV1224005-dimensions.gif) | Body, terminals and overall geometry |
| [RKJXV1224005 mounting holes](research-2026-09-09/ALPS-RKJXV1224005-mounting.gif) | PCB hole layout; observe the manufacturer's mounting-side view |
| [RKJXV1224005 lever](research-2026-09-09/ALPS-RKJXV1224005-lever.gif) | Cap-interface geometry |
| [EC11E15244G1 dimensions](research-2026-09-09/ALPS-EC11E15244G1-dimensions.gif) | Exact ALPS encoder outline |
| [EC11E15244G1 mounting holes](research-2026-09-09/ALPS-EC11E15244G1-mounting.gif) | Exact ALPS encoder PCB hole layout |

**Encoder alternative:** [ALPS EC11E15244G1](https://tech.alpsalpine.com/e/products/detail/EC11E15244G1/) has a 20 mm flat shaft, 30 detents, 15 pulses and a push switch. An [AliExpress listing naming this exact model](https://www.aliexpress.com/item/1005008895804725.html) advertises **2 pieces** ([listing evidence](https://www.pricearchive.org/aliexpress.com/item/1005008895804725)). Five packs would yield ten encoders, but **does not meet your 10-piece-lot requirement**. It is an alternative only if you accept that exception; shipping is also unverified. The saved ALPS drawings do **not** qualify the generic K06 lot.

Bare controls need soldering to a carrier PCB, including their mechanical support tabs. The assembled carrier can then form a plug-in kit. They will not plug straight into the five-pin breakout sockets shown in generic Arduino wiring diagrams.

## DipTrace libraries and 3D models

**No exact native DipTrace symbol/footprint set was verified for the AliExpress lots.** These are the useful resources actually found:

| Part | Resource | Status and applicability |
|---|---|---|
| ALPS EC11E15244G1 | [ALPS product page](https://tech.alpsalpine.com/e/products/detail/EC11E15244G1/) | Exact dimension/mounting drawings saved. Page offers 3D CAD under member access; model not downloaded or checked. |
| ALPS RKJXV122400R | [SnapMagic symbol/footprint/3D page](https://www.snapeda.com/parts/RKJXV122400R/ALPS/view-part/) | Page advertises CAD resources but previews/pinout were unavailable. No import or geometry validation performed; not a verified 4005 model. ALPS also offers a member CAD route for the R part. |
| Waveshare ESP32-S3-Zero | [Official hardware resources](https://docs.waveshare.com/ESP32-S3-Zero/Resources-And-Documents) · [saved STEP](research-2026-09-09/Waveshare-ESP32-S3-Zero-v2.stp) · [saved dimension drawing](research-2026-09-09/Waveshare-ESP32-S3-Zero-dimensions.jpg) | **Manufacturer STEP downloaded**, file header checked. Drawing is 18 × 23.5 mm, 2.54 mm side pitch, 15.24 mm row spacing. These files belong to Waveshare's board; no generic SuperMini match is established. |
| Adafruit MAX98357A, product 3006 | [Module drawings and Eagle files](https://learn.adafruit.com/adafruit-max98357-i2s-class-d-mono-amp/downloads) · [STEP repository](https://github.com/adafruit/Adafruit_CAD_Parts/tree/main/3006%20MAX98357) | Manufacturer module CAD available. Applies to Adafruit's board, not automatically K04's clone. |
| PCM5102A chip | [TI product/CAD page](https://www.ti.com/product/PCM5102A) | Ultra Librarian link for IC symbol, package footprint and 3D. A carrier for K03 needs a module footprint instead. |
| MAX98357A chip | [Analog Devices product/CAD page](https://www.analog.com/en/products/MAX98357A.html) | Ultra Librarian/SamacSys resources by package. Select the exact package only for a future board using the bare IC. |
| Other candidate boards | Exact module libraries not verified | Draw the module outline, header pads, mounting holes and keepouts from its supplier drawing after the SKU is fixed. |

DipTrace supports importing other CAD formats. SamacSys explains that its former DipTrace downloads used PADS files and that these now reside in its PADS folder. Treat this as an **import route**, not native DipTrace availability. Follow the installed version's documentation, import footprint and component together, then check pin numbers, hole sizes and model alignment. [SamacSys explanation](https://www.samacsys.com/supporting-diptrace/) · [DipTrace import documentation](https://www.diptrace.com/support/tutorials/help_html/).

## Other parts needed to finish ten kits

These quantities are procurement allowances where the carrier has not yet been designed. Search links are explicitly **searches**, not checked product listings. Shipping and drawings remain open for these items too.

| Item | Quantity for ten kits | Buying specification / link |
|---|---|---|
| Encoder knobs | **10**, one 10-pack | [10-piece listing](https://www.aliexpress.com/item/33003636792.html) · [listing evidence](https://alitools.io/en/showcase/10pcs-6mm-shaft-hole-amplifier-knob-for-encoder-potentiometer-knobs-33003636792). Match the selected 6 mm shaft profile, bore depth and push clearance; obtain outside dimensions. |
| Joystick caps | **10**, if not supplied | Match the exact ALPS lever drawing. [AliExpress search](https://www.aliexpress.com/w/wholesale-10pcs-joystick-thumbstick-cap.html). Do not assume PS4/PS5/Xbox caps are interchangeable. |
| Male header strips | Budget **20 × 1×40**, 2.54 mm | Two 10-packs; deduct headers included with modules. [Search](https://www.aliexpress.com/w/wholesale-10pcs-1x40-2.54-male-header.html). Final cut lengths depend on selected boards. |
| Female socket strips | Budget **20 × 1×40**, 2.54 mm | Two [10-piece lots](https://www.aliexpress.com/item/1005013054690432.html) · [listing evidence](https://www.pricearchive.org/aliexpress.com/item/1005013054690432). Confirm socket height/drawing. Cutting ordinary sockets may sacrifice a position; pin budget is provisional. |
| USB data cables | **10** | USB-A to USB-C with USB 2.0 data conductors; choose a stated length such as 0.5 m. [Search](https://www.aliexpress.com/w/wholesale-10pcs-usb-a-usb-c-data-cable.html). Charge-only cables cannot flash or export files. |
| Power supply | **10 if each kit needs one** | Regulated 5 V supply; initial engineering allowance 2 A per kit, subject to power-path design and measured load. [Search](https://www.aliexpress.com/w/wholesale-10pcs-5v-2a-usb-power-supply.html). Plug type and destination remain open. |
| Speaker connectors/leads | **10 mating pairs** if detachable | Choose one exact connector, e.g. genuine JST-PH 2 mm, with a supplier drawing and adequate current rating. [Search](https://www.aliexpress.com/w/wholesale-10sets-jst-ph-2.0-2pin-wire.html). Terminal blocks supplied on the amp can remove this requirement. |
| Headphone sockets | **10 if absent from chosen headphone amp** | 3.5 mm stereo TRS socket. [Search](https://www.aliexpress.com/w/wholesale-10pcs-3.5mm-stereo-pcb-jack.html). Select exact part and pinout before drawing PCB; the DAC's existing socket remains line-out unless rerouted. |
| Internal wire/harnesses | **10 sets**, final lengths pending | Short signal wiring plus suitably sized power/speaker wiring. [Search](https://www.aliexpress.com/w/wholesale-10pcs-dupont-jumper-wire-set.html). Bare controls mount on the carrier; jumpers alone do not mount them. |
| Carrier PCBs | **10 assembled carriers** | **Not ready to order.** The repository has no finished carrier layout/manufacturing files. Bare control footprints, sockets, power distribution and mounting must be designed first. Final carrier resistors/capacitors/connectors require its schematic BOM. |
| I2C pull-up resistors | Allow **20 × 4.7 kΩ**; buy a 100-pack | Only populate if needed after checking module pull-ups. [Search](https://www.aliexpress.com/w/wholesale-100pcs-4.7k-resistor.html). Package is a carrier-design decision. |
| Supply/ADC/filter passives | **TBD by carrier schematic** | Reserve decoupling and bulk capacitance, and control filtering as required. Do not order an invented final value/package list before the power and carrier circuits exist. |
| Enclosures/lids | **10 printed pairs** | Existing [3D designs](../3d/README.md) require the final part dimensions. Select handheld/ocarina/cup before manufacturing. |
| Screws and mounting hardware | At least **40 lid screws** for handheld; allow a 100-pack | Handheld CAD has four lid screws per kit; module and carrier fixings are additional. M2-family hardware is the current intent, but length/type depend on final bosses. [Search](https://www.aliexpress.com/w/wholesale-100pcs-m2-self-tapping-screws.html). |
| Microphone/speaker gasket material | **10 cut sets** | Cut foam/gasket pieces to the actual mic port and speaker rim. Enclosure-dependent; protect the microphone opening from blockage. |

No external microSD card, SD module or crystal is specified for the current module build: firmware stores songs in the ESP32's onboard flash, and the modules provide their chip support circuits.

## Battery operation needs a completed power design

The enclosure contains placeholders for a 1S battery and TP4056 board, but the repository does not define a finished battery power path. The complete portable version additionally needs **10 protected 1S cells**, **10 suitable charging/power-path assemblies**, **10 5 V converters if not integrated**, **10 switches**, and matching battery harnesses. Battery size/capacity, charge current and connector polarity must be fixed together.

A TP4056 module alone does not supply a regulated 5 V rail or establish load sharing. Treat battery, charger and boost modules as **design holds**, not an approved three-item shopping recipe. Charge-while-playing also needs deliberate power-path support. [Microchip explanation of load sharing and power-path management](https://ww1.microchip.com/downloads/en/AppNotes/01149c.pdf).

Search leads for later: [protected 1S LiPo lots](https://www.aliexpress.com/w/wholesale-10pcs-3.7v-lipo-battery-protected.html) · [charger/power-path modules](https://www.aliexpress.com/w/wholesale-lipo-power-path-charger-5v-boost.html) · [switch lots](https://www.aliexpress.com/w/wholesale-10pcs-slide-switch.html). None has been qualified for shipping, documentation or this power budget.

## Documented alternatives if generic-board drawings cannot be obtained

These help meet the mechanical-documentation requirement. **Ten-piece lots and free shipping have not been established for these alternatives.** Substitution changes the carrier/enclosure design.

| Function | Documented part | Useful evidence |
|---|---|---|
| MCU | [Waveshare ESP32-S3-Zero](https://www.waveshare.com/product/esp32-s3-zero.htm) | 4 MB flash + 2 MB PSRAM; manufacturer schematic, dimension drawing and STEP. A firmware-compatible candidate by chip configuration, subject to pinout/revision and hardware checks. |
| Speaker amp | [Adafruit MAX98357A, 3006](https://www.adafruit.com/product/3006) | 19.4 × 17.8 × 3.0 mm product dimensions; dimensioned fab print, schematic, Eagle files and STEP. Account separately for fitted headers/terminal blocks. |
| IMU | [Adafruit MPU6050, 3886](https://www.adafruit.com/product/3886) | 26.0 × 17.8 × 4.6 mm; [fab print, schematic and Eagle files](https://learn.adafruit.com/mpu6050-6-dof-accelerometer-and-gyro/downloads). Different PCB from GY-521. |
| Distance | [Pololu VL53L0X carrier, 2490](https://www.pololu.com/product/2490) | Approximately 13 × 18 × 2 mm without headers; regulator, I2C level shifting and mounting information. |
| OLED | [Joy-IT SBC-OLED01 documentation](https://www.joy-it.net/files/files/Produkte/SBC-OLED01/SBC-OLED01_Datasheet_2022-01-06.pdf) | SSD1306 128×64; specified 27.5 × 27.7 × 11.2 mm. Confirm exact revision and full mounting drawing when sourcing. |
| Speaker | [Same Sky CMS-4012-34L200-X7](https://www.sameskydevices.com/product/audio/speakers/miniature-%2810-mm~40-mm%29/cms-4012-34l200-x7) | 40 × 40 × 12 mm, 4 Ω, 3 W nominal; manufacturer's datasheet. Its 12 mm depth differs substantially from the current 5.5 mm enclosure placeholder. |

## Build findings that affect the order

These findings come from the repository's README, firmware and enclosure files, checked on the research date:

- **MPU6050 is the intended motion sensor.** It contains a gyro and accelerometer, but `firmware/main/imu.c` currently derives tilt from accelerometer readings only. No separate gyroscope is needed for this implementation.
- **VL53L0X is the implemented distance sensor.** Although the pin-map document mentions VL53L1X too, `firmware/main/tof.c` uses VL53L0X registers and model ID.
- **The joystick enclosure model is still KY-023-style.** `3d/parts.scad` explicitly labels all its sizes as typical/unmeasured; it cannot establish fit for the bare ALPS joystick or a supplier's modules.
- **Headphones require additional hardware.** TI specifies PCM5102A line loads down to 1 kΩ; ordinary 16–64 Ω headphones need a suitable amplifier. K11 and its socket/coupling requirements therefore remain in the complete-kit scope. [TI specification](https://www.ti.com/lit/ds/symlink/pcm5102a.pdf).
- **Power documentation conflicts.** The pin-map introduction says all modules use 3V3, while its PCM5102A section specifies 5 V input to the regulator-equipped DAC board. Resolve this against actual board schematics; do not power a bare PCM5102A chip with 5 V. Budget the speaker amplifier separately from the tiny board's 3.3 V regulator. MAX98357A's approximately 3 W capability assumes the appropriate 5 V supply/load conditions. [TI DAC documentation](https://www.ti.com/product/PCM5102A) · [Analog Devices amplifier documentation](https://www.analog.com/en/products/MAX98357A.html).

## Information needed to qualify the shortlist

1. Delivery **country and postcode**, and the intended meaning of “AliExpress special” if it is not Choice.
2. Confirmation that the target is **ten complete kits**, with only the encoder/joystick bare.
3. A readable selected-variant listing/cart view for the promising products, showing pack size and shipping. Exact supplier drawings can then be matched against the part and board photos.
4. Carrier, headphone and portable-power decisions before the remaining manufacturing BOM can be finalized.

Seller message you can copy (draft only; not sent):

> I need one lot of 10 identical pieces for a custom PCB. Please confirm the exact manufacturer part number and PCB revision, and provide a dimensioned drawing including all pin/hole positions and total height. For the encoder and joystick I require the bare component, without a breakout board. Please confirm which caps, nuts, headers and connectors are included, and whether a schematic symbol, PCB footprint or STEP model is available for this exact item.

The companion [CSV](purchasing-kit.csv) separates required quantity, advertised pack size, dimensional-document status and verification fields. The original placeholder `parts/bom.csv` has been preserved.

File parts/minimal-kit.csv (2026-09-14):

id | part | scope | qty_per_kit | qty_for_10_kits | advertised_pack_options | target_pieces_per_pack | target_number_of_packs | purchase_url | link_type | listing_evidence_url | documentation_status | documentation_url | cad_status | choice_status | shipping_status | verified_lot_price | currency | verified_shipping_cost | verification_date | notes
M01 | ESP32-S3 SuperMini ESP32-S3FH4R2 | Current seven-part kit | 1 | 10 | 1-10 | 10 | 1 | https://www.aliexpress.com/item/1005012191736844.html | Candidate product listing | https://www.pricearchive.org/aliexpress.com/item/1005012191736844 | Exact module drawing needed | https://docs.waveshare.com/ESP32-S3-Zero/Resources-And-Documents | Waveshare reference only; exact SuperMini library not verified | Unverified | Unverified |  |  |  | 2026-09-09 | One per kit; target one lot of 10. Exact selected variant, headers, shipping and drawing match remain unverified.
M02 | PCM5102A I2S DAC PURPLE board with audio jack | Current seven-part kit | 1 | 10 | 1-10 | 10 | 1 | https://www.aliexpress.com/item/1005010369195534.html | Candidate product listing | https://www.pricearchive.org/aliexpress.com/item/1005010369195534 | Chip datasheet available; exact purple board revision/drawing unverified | https://www.ti.com/lit/ds/symlink/pcm5102a.pdf | Chip CAD on TI; module CAD not verified | Unverified | Unverified |  |  |  | 2026-09-09 | One per kit; target one lot of 10. Exact selected variant, headers, shipping and drawing match remain unverified.
M03 | KY-023-style joystick BOARD with fitted pins and cap | Current seven-part kit | 1 | 10 | 1/5/10 | 10 | 1 | https://www.aliexpress.com/item/1005008298413198.html | Candidate product listing | https://ms.pricearchive.org/aliexpress.com/item/1005008298413198 | Joy-IT module documentation is reference only; exact seller PCB drawing and fitted pins unverified | https://www.joy-it.net/en/products/COM-KY023JM | Exact module footprint/STEP not verified; bare ALPS drawings do not apply | Unverified | Unverified |  |  |  | 2026-09-09 | One per kit; target one lot of 10. Exact selected variant, headers, shipping and drawing match remain unverified.
M04 | Bare EC11 encoder with push switch | Current seven-part kit | 1 | 10 | 10 | 10 | 1 | https://www.aliexpress.com/item/1005005239756119.html | Candidate product listing | https://www.pricearchive.org/aliexpress.com/item/1005005239756119 | Exact MPN and seller drawing needed |  | Generic EC11 cannot establish exact footprint | Unverified | Unverified |  |  |  | 2026-09-09 | One per kit; target one lot of 10. Exact selected variant, headers, shipping and drawing match remain unverified.
M05 | Round SIX-PIN I2S microphone board; INMP441 assumed | Current seven-part kit | 1 | 10 | 1/5/10 | 10 | 1 | https://www.aliexpress.com/item/1005009006830769.html | Candidate product listing | https://www.pricearchive.org/aliexpress.com/item/1005009006830769 | Chip datasheet only; round six-pin variant and board dimensions unverified | https://invensense.tdk.com/wp-content/uploads/2015/02/INMP441.pdf | Not verified | Unverified | Unverified |  |  |  | 2026-09-09 | One per kit; target one lot of 10. Exact selected variant, headers, shipping and drawing match remain unverified.
M06 | SSD1306 0.96 inch 128x64 4-pin I2C OLED | Current seven-part kit | 1 | 10 | 10 | 10 | 1 | https://www.aliexpress.com/item/1005008169257099.html | Candidate product listing | https://www.pricearchive.org/aliexpress.com/item/1005008169257099 | Exact module drawing needed |  | Not verified | Unverified | Unverified |  |  |  | 2026-09-09 | One per kit; target one lot of 10. Exact selected variant, headers, shipping and drawing match remain unverified.
M07 | MPU6050 GY-521 IMU breakout | Current seven-part kit | 1 | 10 | 10 | 10 | 1 | https://www.aliexpress.com/item/1005011896641210.html | Candidate product listing | https://www.pricearchive.org/aliexpress.com/item/1005011896641210 | Chip datasheet only; module drawing needed | https://product.tdk.com/system/files/dam/doc/product/sensor/mortion-inertial/imu/data_sheet/mpu-6000-datasheet1.pdf | Not verified for GY-521 lot | Unverified | Unverified |  |  |  | 2026-09-09 | One per kit; target one lot of 10. Exact selected variant, headers, shipping and drawing match remain unverified.

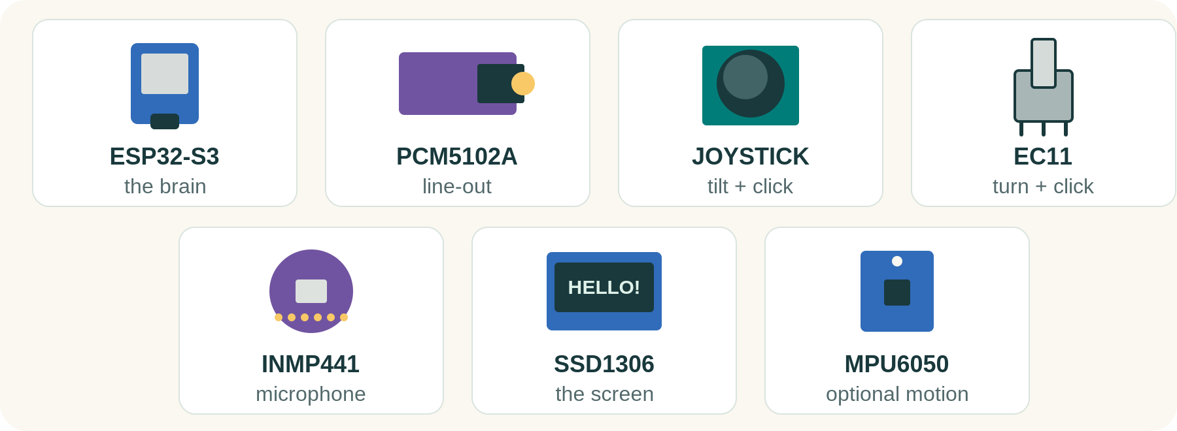
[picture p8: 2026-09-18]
docs/assembly/assets/parts.png

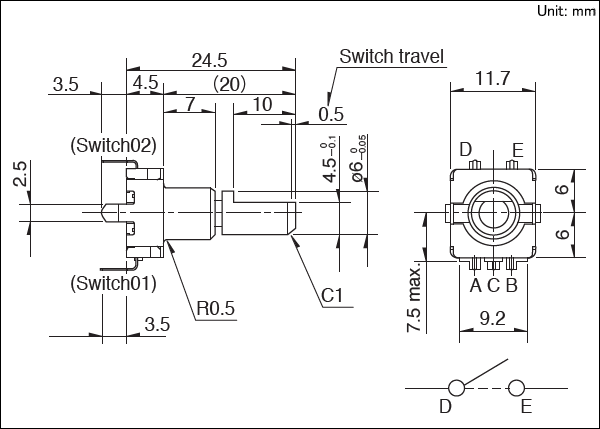
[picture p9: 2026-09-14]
parts/research-2026-09-09/ALPS-EC11E15244G1-dimensions.gif

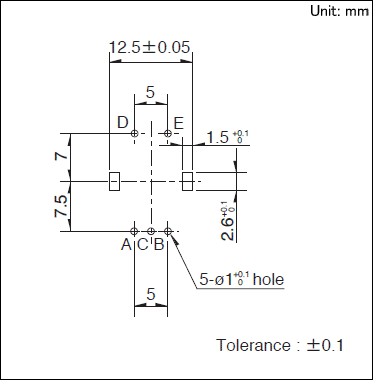
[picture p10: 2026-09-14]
parts/research-2026-09-09/ALPS-EC11E15244G1-mounting.gif

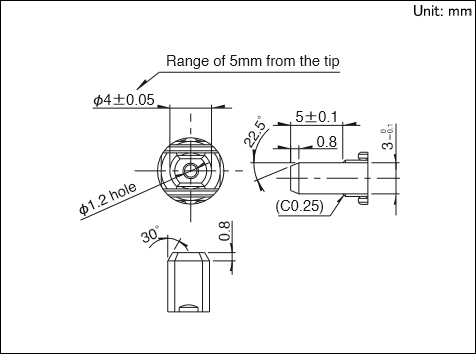
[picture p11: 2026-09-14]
parts/research-2026-09-09/ALPS-RKJXV1224005-lever.gif

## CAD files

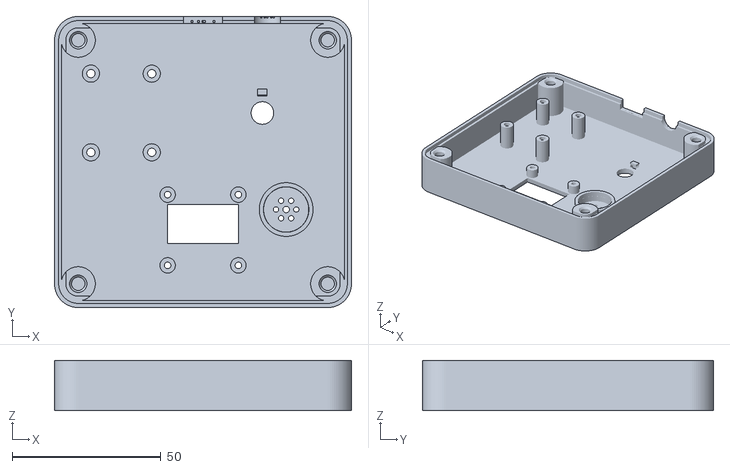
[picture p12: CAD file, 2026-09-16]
enclosure/out/shell.stl
100.0 x 98.0 x 17.0

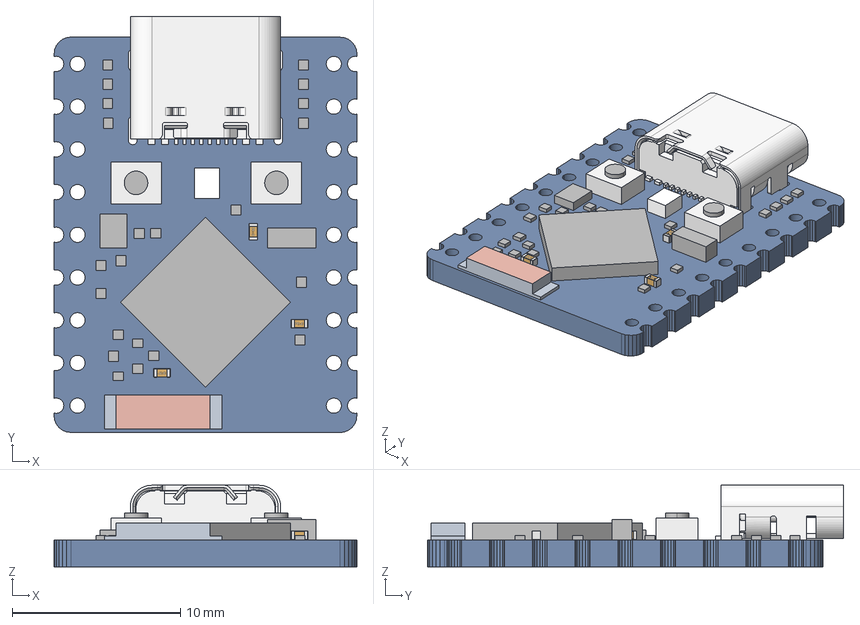
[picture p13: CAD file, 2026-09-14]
parts/research-2026-09-09/Waveshare-ESP32-S3-Zero-v2.stp
18.0 x 24.7 x 4.85 mm
BOARD
EXTRUDED-21020 x 13
EXTRUDED-21415 x 7
3_1_A x 3
EXTRUDED-58116 x 2
EXTRUDED-58651
EXTRUDED-59046
EXTRUDED-59609
TYPE-C_16PIN-9X3X7_3
PRT0001
C3
BUTTON-2X3XH1_5

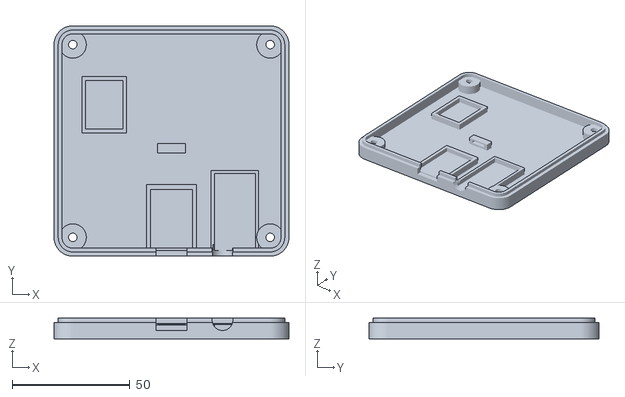
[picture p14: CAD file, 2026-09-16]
enclosure/out/lid.stl
100.0 x 98.0 x 8.80

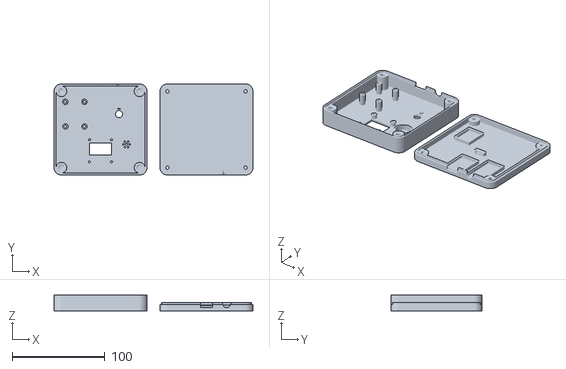
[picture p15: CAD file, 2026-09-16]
enclosure/out/print_bed.stl
214.0 x 98.0 x 17.0

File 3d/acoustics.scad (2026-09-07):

// Acoustic helpers. Units: mm for lengths, mm^2 area, mm^3 volume, Hz.
// See docs/acoustics.md for where the formulas come from and their limits.

c_sound = 343000;   // mm/s at 20 C

// Effective neck length: physical length plus end corrections on both ends
function neck_eff(L, d) = L + 1.7 * d / 2;

// Helmholtz resonance of a cavity V with one opening of area A and neck length L
function helmholtz_f(V, A, L, d) = c_sound / (2 * PI) * sqrt(A / (V * neck_eff(L, d)));

// Cavity volume that puts the resonance at f for a given opening
function helmholtz_V(f, A, L, d) = A / (neck_eff(L, d) * pow(2 * PI * f / c_sound, 2));

// Ocarina: several openings in parallel add their A/L_eff terms
function conductance(A, L, d) = A / neck_eff(L, d);
function ocarina_f(V, cond_sum) = c_sound / (2 * PI) * sqrt(cond_sum / V);

// Tube resonances
function tube_closed_f(L, n=1) = (2*n - 1) * c_sound / (4 * L);   // closed one end, odd harmonics
function tube_open_f(L, n=1)   = n * c_sound / (2 * L);            // open both ends

// Round hole area
function circle_area(d) = PI * d * d / 4;

// Diameter of a hole with area A
function circle_d(A) = 2 * sqrt(A / PI);

// Hole diameter that raises an ocarina from f_closed to f_target when opened,
// given the chamber volume V and the wall thickness t. Solved numerically
// because the end correction depends on the diameter.
function ocarina_hole_d(V, cond_closed, f_target, t, d=3, i=0) =
    i > 40 ? d :
    let(f = ocarina_f(V, cond_closed + conductance(circle_area(d), t, d)))
    abs(f - f_target) < 0.5 ? d :
    ocarina_hole_d(V, cond_closed, f_target, t, d * (f < f_target ? 1.03 : 0.97), i + 1);

function note_freq(midi) = 440 * pow(2, (midi - 69) / 12);

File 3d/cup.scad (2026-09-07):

// Option C: beatbox cup on a wand. The mic sits at the bottom of a cup you
// press to your mouth, so it hears you 15-20 dB above the room and nothing
// from the speaker. The cup is a Helmholtz resonator only when the lips seal
// it; the echo below prints where it sits (mid-vowel range, not kick range,
// see docs/acoustics.md). The handle carries, from the cup outwards, the
// joystick under the thumb, the OLED, the encoder, then the ESP with USB-C
// out of the end. Open underneath; a flat lid closes it.
include <parts.scad>
include <acoustics.scad>

show_parts = true;
wall = 2.0;
cup_d = 44; cup_depth = 28;            // inner
hnd_w = 34; hnd_h = 20; hnd_l = 130; hnd_r = 6;

echo(str("cup sealed by the lips: ~", round(helmholtz_f(PI*pow(cup_d/2,2)*cup_depth, PI*pow(8,2), 15, 16)), " Hz through a 16 mm lip gap; open cup: quarter-wave ", round(tube_closed_f(cup_depth)), " Hz"));

module cup() {
    difference() {
        union() {
            cylinder(d=cup_d + 2*wall, h=cup_depth + wall);
            // mic pocket on the back of the cup
            translate([-mic_w/2 - 2, 12 - mic_l/2 - 2, -mic_t - wall]) cube([mic_w + 4, mic_l + 4, mic_t + wall]);
        }
        translate([0, 0, wall]) cylinder(d=cup_d, h=cup_depth + 1);
        // mic port in the cup floor, off-centre so the OLED can sit behind
        translate([0, 12, -1]) cylinder(d=mic_hole_d, h=wall + 2);
        translate([-mic_w/2, 12 - mic_l/2, -mic_t - wall - 1]) cube([mic_w, mic_l, mic_t + 1]);
        // drain / pressure slots so the seal does not pop the mic
        for (r = [0 : 60 : 300]) rotate([0, 0, r]) translate([cup_d/2 - 1, -0.5, cup_depth - 6]) cube([wall + 2, 1, 4]);
    }
    if (show_parts && $preview) %translate([-mic_port_xy[0], 12 - mic_port_xy[1], -mic_t]) inmp441();
}

joy_y = hnd_l - 18; oled_y = hnd_l - 64; enc_y = hnd_l - 84;
module handle() {
    translate([-hnd_w/2, -cup_d/2 - hnd_l, -hnd_h]) difference() {
        rounded_box([hnd_w, hnd_l + 10, hnd_h], hnd_r);
        translate([wall, wall, -eps]) rounded_box([hnd_w - 2*wall, hnd_l + 10 - 2*wall, hnd_h - wall], hnd_r - wall);
        translate([hnd_w/2, joy_y, hnd_h - wall - joy_t - joy_base_h + 1.5]) joystick(cut=true);
        translate([hnd_w/2 - oled_w/2, oled_y, hnd_h - wall - oled_t - oled_glass_t]) oled_096(cut=true);
        translate([hnd_w/2, enc_y, hnd_h - wall - enc_body_h]) encoder(cut=true);
        translate([hnd_w/2 - esp_w/2, 1, 3]) rotate([0, 0, 180]) translate([-esp_w, -esp_l, 0]) esp32_zero(cut=true);
    }
    if (show_parts && $preview) translate([-hnd_w/2, -cup_d/2 - hnd_l, -hnd_h]) {
        %translate([hnd_w/2, joy_y, hnd_h - wall - joy_t - joy_base_h + 1.5]) joystick();
        %translate([hnd_w/2 - oled_w/2, oled_y, hnd_h - wall - oled_t - oled_glass_t]) oled_096();
        %translate([hnd_w/2, enc_y, hnd_h - wall - enc_body_h]) encoder();
    }
}

cup();
handle();

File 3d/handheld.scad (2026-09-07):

// Option A: handheld slab. OLED and controls on top, speaker in a sealed
// sub-box, mic on the top edge, USB-C at the bottom edge, battery under
// the lid. The safe, Game-Boy-shaped choice.
//
// Print: shell top-face down, lid flat. Renders shell + lid side by side;
// set part = "shell" or "lid" to export one STL.
include <parts.scad>
include <acoustics.scad>

part = "both";       // "shell" | "lid" | "both"
show_parts = true;   // draw component placeholders in preview

L = 118; W = 74; H = 26; R = 8; wall = 2.0;
lid_t = 2.0;

// placement (x, y from the shell corner, parts sit under the top plate)
oled_pos = [9, 40];
enc_pos  = [100, 56];
joy_pos  = [96, 22];
spk_pos  = [31, 24];
esp_pos  = [L/2 - esp_w/2, 1.5];              // USB-C out of the bottom wall
mic_pos  = [L/2, W];                          // port through the top edge wall
z_top_in = H - wall;                          // underside of the top plate

module placed_parts(cut=false) {
    translate([oled_pos[0], oled_pos[1], z_top_in - oled_t - oled_glass_t]) oled_096(cut);
    translate([enc_pos[0], enc_pos[1], z_top_in - enc_body_h]) encoder(cut);
    translate([joy_pos[0], joy_pos[1], z_top_in - joy_t - joy_base_h + 1.5]) joystick(cut);
    translate([spk_pos[0], spk_pos[1], z_top_in - spk_h]) speaker(cut);
    translate([esp_pos[0], esp_pos[1], lid_t + 1]) rotate([0, 0, 180]) translate([-esp_w, -esp_l, 0]) esp32_zero(cut);
    // mic PCB stands vertically against the inside of the top wall, port through it
    translate([mic_pos[0] - mic_w/2, W - wall, H/2 - mic_l/2]) rotate([90, 0, 0]) translate([0, 0, -mic_t]) inmp441(cut);
}

module shell() {
    difference() {
        union() {
            difference() {
                rounded_box([L, W, H], R);
                translate([wall, wall, -eps]) rounded_box([L - 2*wall, W - 2*wall, H - wall], R - wall);
            }
            // screw posts in the corners
            for (x = [R, L - R], y = [R, W - R]) translate([x, y, 0]) cylinder(d=6, h=H - wall);
            // sealed speaker box: a ring from the top plate down to the lid line
            translate([spk_pos[0], spk_pos[1], 0]) difference() {
                cylinder(d=spk_d + 6, h=H - wall);
                translate([0, 0, -eps]) cylinder(d=spk_d + 2, h=H);
            }
            // OLED and joystick posts hang from the top plate
            translate([oled_pos[0], oled_pos[1], z_top_in - oled_t - oled_glass_t]) oled_posts(h=oled_t + oled_glass_t + eps);
            translate([joy_pos[0], joy_pos[1], z_top_in - joy_t - joy_base_h + 1.5]) joystick_posts(h=joy_t + joy_base_h);
        }
        placed_parts(cut=true);
        translate([spk_pos[0], spk_pos[1], H - wall]) speaker_grille(t=wall);
        // pop slots around the mic port in the top edge wall
        translate([mic_pos[0], W - wall/2, H/2]) rotate([90, 0, 0]) pop_grille(14, 10, t=wall + 1);
        // headphone jack out of the left wall (DAC lies along it)
        translate([-1, 30, 9]) rotate([0, 90, 0]) cylinder(d=dac_jack_d + 0.6, h=wall + 2);
        for (x = [R, L - R], y = [R, W - R]) translate([x, y, -eps]) cylinder(d=1.7, h=8);
    }
}

module lid() {
    difference() {
        rounded_box([L, W, lid_t], R);
        for (x = [R, L - R], y = [R, W - R]) translate([x, y, -eps]) cylinder(d=2.3, h=lid_t + 1);
    }
    // battery cradle
    translate([L/2 - bat_w/2 - 1.5, W/2 - bat_l/2 - 1.5, lid_t]) difference() {
        cube([bat_w + 3, bat_l + 3, 4]);
        translate([1.5, 1.5, -eps]) cube([bat_w, bat_l, 5]);
    }
}

if (part == "shell" || part == "both") {
    shell();
    if (show_parts && $preview) %placed_parts();
}
if (part == "lid") lid();
if (part == "both") translate([L + 15, 0, 0]) lid();

echo(str("speaker box volume ~", round(PI * pow((spk_d + 2)/2, 2) * (H - wall - spk_h) / 1000), " cm3 (sealed)"));

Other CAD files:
3d/ocarina.scad
3d/parts.scad
enclosure/enclosure.scad
enclosure/parts.scad
enclosure/print_bed.scad

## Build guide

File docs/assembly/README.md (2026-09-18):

# Make a little noise.

The friendly ESP32-S3 SuperMini assembly guide

[Download the printable PDF](../../output/pdf/esp32-s3-supermini-assembly-guide.pdf) · [Open the browser checklist](index.html) · [SVG and PNG artwork](assets/)

> On GitHub, download the repository and open `docs/assembly/index.html` locally for the interactive version. No server or internet connection is needed to read it.

## Contents

1. [Make a little noise.](#hello)
2. [Small steps. Happy beeps.](#start)
3. [Seven little teammates.](#parts)
4. [Two rails. One ground.](#power)
5. [Teach it the test tune.](#firmware)
6. [Hello, tiny screen.](#display)
7. [Say hello. Watch it listen.](#microphone)
8. [Meet the purple sound card.](#dac)
9. [Twist. Tilt. Click.](#controls)
10. [Earn your first-sound badge.](#bench)
11. [Print. Measure. Dry-fit.](#case-prep)
12. [Build the shell sandwich.](#case-assembly)
13. [Your tiny band is ready.](#jam)
14. [Add extras after the win.](#extras)
15. [One clue at a time.](#rescue)
16. [Your pocket pin map.](#reference)

## 01. Make a little noise.

*LET'S BUILD A MUSIC MACHINE*

A microphone, a tiny screen, two playful controls, and a whole lot of sound. Build your kit one small win at a time.

Illustrated layout of the current case. USB-C and line-out exit the front edge.

> **YOUR FINISH LINE**
>
> A USB-powered instrument that hears your voice and plays through powered speakers, an audio interface, or a separate headphone amp.

This is a guide to the current wired prototype. The socketed carrier PCB is not finished. Some parts need soldered headers or prepared leads, and the printed case must be checked against your exact boards.

Follow the numbered missions, tick the checkpoints, and keep the case open until the electronics pass. First electronics build? Invite an experienced maker for the soldering and power checks.

Inside: a parts field guide, labeled wiring diagrams, firmware steps, case assembly, a first-beat challenge, and a rescue page. All wiring illustrations use signal names, not physical pin positions.

## 02. Small steps. Happy beeps.

*00 / CHOOSE YOUR ADVENTURE*

Work on a clear, nonconductive table. Give yourself an unhurried afternoon for the electronics, plus printing and software setup time.

| Mission | Your small win | Page |
| --- | --- | --- |
| Prepare | Identify every module and power pin | 3-4 |
| Wake up the brain | Flash the hardware-test app | 5 |
| Add the senses | Screen on; mic responding | 6-7 |
| Make sound | Wire the DAC and controls; pass the bench test | 8-10 |
| Give it a home | Dry-fit, mount, route, close | 11-12 |
| Play | Make a beat in JAM | 13 |

### Put these within reach

- A computer, USB-C data cable, and powered speaker with AUX/line input (or an audio interface / headphone amplifier). A charge-only cable cannot flash the board.
- Short jumper wires with ends that fit your headers; a breadboard or insulated distribution board for shared connections. Check whether breadboard power rails are split.
- A multimeter, small screwdrivers, tape labels, wire cutters, and a ruler or calipers. Use insulated wire and strain relief for the final harness.
- For unfinished headers, DAC straps, or the bare EC11: a soldering iron, stand, solder, ventilation, and heat-shrink. Get hands-on help if these are new to you.

> **THE ONE HABIT THAT SAVES BOARDS**
>
> Unplug USB and every other power source before adding, moving, soldering, or checking continuity on a wire. Power up only after checking the new connections.

Solderless means the connections are already prepared: headers fitted, DAC straps set, and the encoder on an adapter or harness. Loose pins pushed through bare holes are not reliable electrical joints.

- [ ] I have a data cable and a suitable line-level listening device.
- [ ] I know which parts need soldering or prepared leads.

## 03. Seven little teammates.

*01 / MEET THE BAND*

Match the printed labels and the exact board version. Color and shape are clues, never proof of a pinout.

Simplified identification drawings; not to scale and not a footprint or pin-order reference.

| Qty | Part | Check before wiring |
| --- | --- | --- |
| 1 | ESP32-S3 SuperMini | ESP32-S3FH4R2; 4 MB flash, 2 MB PSRAM; USB-C |
| 1 | PCM5102A DAC | Purple jack board; verify VIN rating and all four straps |
| 1 | KY-023-style joystick | Board with fitted pins and cap; VRx, VRy, SW |
| 1 | Bare EC11 encoder | Push switch, matching nut/washer/knob; prepared leads |
| 1 | INMP441 microphone | Round six-pin board; confirm actual chip and pin labels |
| 1 | SSD1306 OLED | 0.96-inch, 128 x 64, four-pin I2C version |
| 1 | MPU6050 / GY-521 | Motion sensor; optional for first sound and JAM |

Also gather wiring, the USB data cable, and a line-out cable. Case hardware is listed on page 11. The MAX98357A speaker amp and VL53L0X distance sensor are optional extras (page 14), not part of this seven-part list.

> **LOOK TWICE, PLUG ONCE**
>
> Some OLEDs swap VCC and GND. Some six-pin microphones use another chip. Seller listings are not verified kit specifications. If a pin or board revision is unclear, identify it before powering it.

- [ ] My modules match this list, and their power pins are readable.

## 04. Two rails. One ground.

*02 / POWER WITHOUT SURPRISES*

A rail is a shared power connection. GND is the common reference. GPIO numbers identify signals on the ESP32, not the position of a header pin.

USB powers the ESP32. Use its labeled rails only after checking your board's power path.

- Use USB-only power for this build. Identify the SuperMini's labeled 3V3, GND, and USB 5V/VBUS pins from the exact board documentation. Do not count header positions from a generic photo.
- Use 3.3 V for the INMP441, joystick, and a verified 3.3 V-compatible OLED. Sensor add-ons must also keep SDA/SCL and all GPIO signals at 3.3 V.
- The documented purple DAC board uses 5 V at VIN through its onboard regulator. Confirm this for your revision before connecting it. Never put 5 V on a bare PCM5102A chip, a 3V3 pin, or an ESP32 GPIO.
- Join every module GND to ESP32 GND. Make shared connections with proper rails or a soldered distribution point; do not cram several wires into one jumper socket.

> **UNPLUGGED CHECK**
>
> Check polarity and continuity of each intended ground connection. Check that 3V3-to-GND and 5V-to-GND are not sustained near-zero-ohm shorts. A brief continuity beep from charging capacitors is not a diagnosis; investigate uncertain readings before power-up.

Leave batteries and charging boards out of this build: the project has no completed battery power-path design. Add only one module per mission, with USB disconnected between changes.

- [ ] I can point to 3V3, GND, and the verified USB 5V rail.
- [ ] The DAC VIN rating is confirmed, and no GPIO wire carries 5 V.

## 05. Teach it the test tune.

*03 / WAKE UP THE BRAIN*

Start with only the ESP32 connected to USB. The hardware-test app lets you add modules gradually and see what is working.

The quickest route needs no toolchain: every release on GitHub ships one file per application that flashes at offset 0. Download kit-test.bin from the latest release, install esptool with pip, and write it. Use the port your system shows: /dev/ttyACM0 on Linux, /dev/cu.usbmodem* on macOS, COM3 or similar on Windows.

```sh
pip install esptool
esptool.py --chip esp32s3 write_flash 0x0 kit-test.bin
```

No terminal? Open esptool-js (linked on page 16) in Chrome or Edge, connect, pick kit-test.bin at address 0x0, and program. Building from source instead: install ESP-IDF v5.5 with ESP32-S3 support, then run tools/app.sh test in the repository and idf.py flash monitor in firmware/. The build fetches components from the internet the first time.

To watch the serial log without ESP-IDF, use any terminal at 115200 baud on the same port. The log names the likely missing wire when something is off. Exit idf.py monitor with Ctrl+].

> **A SUCCESSFUL FIRST BOOT**
>
> Look for the test-app message about a 440 Hz tone for 4 seconds, then mic only. No OLED and no mic data are expected right now. Unplug USB before attaching the display.

Board missing? Try another data cable and USB port; a charge-only cable never shows up. To enter download mode, hold BOOT, tap RESET, then release BOOT and flash again. If your board lacks RESET, hold BOOT while reconnecting USB, then release it. On Linux, follow Espressif's serial-port permissions instructions if access is denied.

- [ ] The hardware-test firmware flashes and its serial log appears.

## 06. Hello, tiny screen.

*04 / GIVE IT A FACE*

Disconnect USB. Read the four OLED labels carefully; their order varies between modules.

Functional connections only. SCL may be printed SCK on an I2C OLED; check the module type.

| OLED label | Connect to |
| --- | --- |
| VCC / VDD | ESP32 3V3, for a verified 3.3 V-compatible module |
| GND | ESP32 GND |
| SDA | GPIO12 |
| SCL | GPIO13 |

Reconnect USB. The serial scan should report 0x3C and the screen should show the test display. The hardware-test app also retries at 0x3D; the main startup path and JAM expect 0x3C. Use a module configured for 0x3C for the finished build.

> **SCREEN STILL DARK?**
>
> Unplug first. Check VCC/GND, then SDA/SCL, then the module's I2C address. A seven-pin SPI display or an SH1106 board is not the specified SSD1306 module. If the image is upside down, Kit firmware > Rotate the OLED 180 degrees controls its orientation.

I2C is a shared two-wire conversation: SDA carries data and SCL keeps time. Later sensors can share these same two signals. The audio wires on the next pages use a different bus called I2S.

- [ ] The screen lights up and the test display updates.

## 07. Say hello. Watch it listen.

*05 / GIVE IT EARS*

Disconnect USB, then add the INMP441. Keep its small sound opening clear of tape, glue, and fingers.

The mic's SCK is the bit clock on GPIO7. Its SD is data going into GPIO10.

| INMP441 label | Connect to |
| --- | --- |
| VDD | 3V3 |
| GND | GND |
| SCK | GPIO7 |
| WS | GPIO8 |
| SD | GPIO10 |
| L/R | GND for this guide; do not leave floating |

Reconnect USB. Wait for the four-second test-tone interval to finish, then speak or hum near the microphone. The level bar and waveform should respond. The serial diagnosis should settle on mic data OK.

> **TINY VICTORY**
>
> The board can hear you even before an audio output is connected. If the firmware reports the RIGHT slot, L/R is high; the firmware supports that too. No data means check mic power, SD, SCK and WS with USB unplugged.

I2S sends sound as numbers. GPIO7 and GPIO8 provide shared timing; the microphone sends its numbers back on GPIO10. The DAC will receive outgoing numbers on a separate wire, GPIO9.

- [ ] My voice changes the level meter and the mic diagnosis is healthy.

## 08. Meet the purple sound card.

*06 / LET THE SOUND OUT*

Disconnect USB. The PCM5102A turns digital audio into a stereo line signal for an amplified listening device.

The two SCK labels mean different things: mic SCK -> GPIO7; DAC SCK -> GND.

| DAC label | Connect to |
| --- | --- |
| VIN | Verified USB 5V rail, only for the regulator-equipped board |
| GND | GND |
| BCK | GPIO7 (shared with mic SCK) |
| LCK / LRCK | GPIO8 (shared with mic WS) |
| DIN | GPIO9 |
| SCK | GND; check whether the board already ties it low |

Check the back-of-board configuration. For the documented purple revision: H1L / FLT = L, H2L / DEMP = L, H3L / XSMT = H, H4L / FMT = L. Confirm each pad's function on your revision; bridge only the selected side, never H to L. Use a prepared board or get soldering help.

> **THIS JACK IS LINE-OUT**
>
> Connect powered speakers, an audio-interface line input, or a separate headphone amplifier. Ordinary headphones and passive speakers need amplification. TI specifies line loads down to 1 kOhm; a headphone-shaped jack does not make this a headphone amp.

Start the listening device at low volume. Connect its line/AUX input, then power the kit. Listen for the four-second 440 Hz tone. After it ends, try a gentle hum; keep the speaker away from the mic to avoid feedback.

- [ ] I hear the startup tone and can hear the mic afterward.

## 09. Twist. Tilt. Click.

*07 / ADD THE PLAYFUL BITS*

Disconnect USB. The joystick uses a breakout board; the bare EC11 needs an identified pinout and a soldered adapter or insulated harness.

Logical EC11 contacts are shown, not their physical order. Mounting tabs are not signal pins.

| Control contact | Connect to |
| --- | --- |
| Joystick VCC / +5V marking | 3V3 for this analog KY-023-style module; never 5 V here |
| Joystick GND / VRy / VRx / SW | GND / GPIO1 / GPIO2 / GPIO3, respectively |
| EC11 A / B / common C | GPIO4 / GPIO5 / GND, respectively |
| EC11 push switch, two contacts | One to GPIO6; the other to GND |

Identify encoder A/B/common and the separate push switch from its drawing or an unplugged continuity test. Do not infer the pin order from this illustration. For an encoder breakout instead, map CLK, DT and SW to GPIO4, GPIO5 and GPIO6; power any onboard pull-ups from 3V3.

Power up without touching the joystick so startup centering can work. Turning the encoder brings up the ENCODER test screen and changes its count. A tap changes effect; a half-second hold changes preset. If turning is reversed, unplug and exchange A/B.

> **SAVE THE JOYSTICK VICTORY FOR JAM**
>
> The test app is mainly a mic/DAC/encoder check. Use JAM on page 13 to verify joystick navigation and click. The firmware rotates the joystick axes for the case mounting; do not swap VRx/VRy just to match the drawing's appearance.

- [ ] Encoder turn and push both work; the joystick is powered from 3V3.

## 10. Earn your first-sound badge.

*08 / THE OPEN-CASE SOUND CHECK*

Keep everything on the bench. A working open build is much easier to assemble and troubleshoot than a mystery inside a closed box.

| Try this | You should get |
| --- | --- |
| Restart the test app | A stable boot, then about 4 seconds of 440 Hz tone |
| Speak gently after the tone | A moving level meter and audible mic signal |
| Watch the serial diagnosis | mic data OK, or mic OK, RIGHT slot |
| Turn the encoder | ENCODER page; count changes consistently |
| Tap, then briefly hold the encoder | Effect changes; then preset changes |
| Leave the kit running for a few minutes | No repeated boot counter increments, dropouts or excess heat |

> **DO NOT CLOSE THE CASE YET**
>
> One failed check is a useful clue. Unplug, inspect that stage, fix it, and repeat the check. The firmware's no shorts between I2S pins message covers only selected signal pairs; it is not a power-rail safety test.

### Label future-you's wires

- Label both ends with the signal name or GPIO number. Color is a helpful extra: use red for 3V3, orange for 5V, and black for GND if you have them.
- Replace flaky temporary connections with fitted headers and insulated, strain-relieved wiring. Keep audio wires short and away from loose metal hardware.
- Photograph your working wiring before moving it into the shell. Leave enough slack to open the case without pulling a connector off.
- If you hear a squeal, lower the external volume and move the speaker away from the mic. This is acoustic feedback, not a challenge to sing louder.

- [ ] All the checks above pass with the case open.
- [ ] Both ends of each wire are labeled and the wiring is documented.
- [ ] USB is unplugged before I begin mechanical assembly.

## 11. Print. Measure. Dry-fit.

*09 / MAKE ITS LITTLE HOME*

The current shell is 100 x 98 x 24 mm. Its cradles model specific module sizes; a board with the same chip can still have a different outline.

Existing OpenSCAD exploded render from this repository. CAD preview, not proof of physical fit.

Use enclosure/out/shell.stl and lid.stl, or the combined print_bed.stl. The exports are already print-oriented: shell top face down, lid bottom face down. Inspect the sliced layers and small bosses before printing.

The design targets a 0.8 mm nozzle, 2.4 mm walls, and 0.32-0.40 mm layers. Start with 3 walls and enough solid layers for 2.4 mm thickness (6 at 0.40 mm or 8 at 0.32 mm), plus 20-30% infill. The CAD intends support-free printing; confirm in your slicer.

| Case hardware | Quantity / starting specification |
| --- | --- |
| Heat-set inserts + lid screws | 4 M3 inserts (OD about 4.6 mm, length 4-5.7 mm); 4 M3 x 10 mm screws |
| OLED / joystick screws | 4 M2 x 4 mm / 4 M2 x 6 mm; verify actual engagement |
| Encoder hardware | Matching M7 nut/washer and 6 mm shaft knob |
| Mic gasket + wire restraint | One foam/silicone ring; small ties or insulated restraint |

> **FIT FIRST, HEAT SECOND**
>
> Try every unpowered board in its cradle, including headers, plug bodies and wire bends. Fit may require CAD changes. Install inserts in the empty shell using your insert/filament supplier's method; practice on scrap and let them cool. Check screw length so tips cannot bottom out, pierce plastic, or hit a board.

- [ ] The dry-fit works and every screw is the right length.

## 12. Build the shell sandwich.

*10 / EVERY PART GETS A PLACE*

USB stays unplugged. Use the drawing as a placement key, then follow the actual mounting features in your printed parts.

Conceptual top-view placement, not a drill template. Both panels use the same front-edge reference.

1. Top shell: fasten the OLED behind its window with four M2 screws. Use light pressure; do not load or pinch the glass.
2. Seat the round mic beside the OLED with its real acoustic port aligned to the grille. Place the gasket around the port; do not cover the opening or force the PCB into the collar.
3. Fit the EC11 through its panel opening, secure the matching washer/nut, and add the knob. Keep enough clearance for the push action. Mount the joystick on its four bosses and check full travel.
4. Lid: seat the ESP32 with USB-C at the front edge. Seat the DAC on the right with its jack facing that same front edge, beside USB. Secure the optional IMU in its own cradle if fitted.
5. Reconnect the labeled harness. Insulate exposed joints, restrain wires, and keep the seam, screw bosses, antenna area and mic port clear. Check connector and pin clearance with the halves gently together.
6. With the case still open on a nonconductive surface, repeat the page 10 sound check. Unplug, align the lip, and close with four lid screws, lightly and evenly. If it resists, reopen and find the obstruction.

- [ ] No wire is pinched; USB/audio plugs seat fully; the knob clicks and stick moves.
- [ ] After closing, the screen, startup tone, microphone and encoder still work.

## 13. Your tiny band is ready.

*11 / MAKE YOUR FIRST BEAT*

Switch to JAM when the hardware checks pass. It is the case-friendly sequencer: six channels, a sampler, and a grid of musical possibilities.

Actual JAM drum-grid render from the repository. The grid contains two bars of 16 steps.

Flash kit-jam.bin from the release the same way as the test image, or from source: tools/app.sh jam in the repository, then idf.py flash in firmware/. JAM is the default application when building from a fresh checkout.

```sh
esptool.py --chip esp32s3 write_flash 0x0 kit-jam.bin
```

| Gesture in JAM | What happens |
| --- | --- |
| Turn encoder / flick joystick | Move the pattern cursor |
| Tap encoder | Toggle the selected grid cell |
| Hold encoder about 0.5 seconds | Next page: PATTERN, MIX, SONG, SETUP |
| Push encoder and turn | Change channel |
| Click joystick | Enter/cycle perform mode; behavior depends on channel |
| Hold encoder 3 seconds | Clear the current channel - use deliberately |

> **THE FIRST-BEAT CHALLENGE**
>
> Select DRUMS on PATTERN. Put kicks on steps 1, 5, 9 and 13 of the first bar; add snare on 5 and 13 and hats on odd steps. Repeat in the second bar. Then switch to BASS and add three notes. Hear that? You built the band.

Verify the joystick moves the cursor and its click changes perform mode. JAM autosaves about two seconds after the last edit; wait a few extra seconds before unplugging. Try a sample next: select MIC and tap to record up to two seconds, then select SAMPLE. Live mic is audible only while MIC is selected.

- [ ] My beat plays, the joystick works, and my pattern returns after a restart.

## 14. Add extras after the win.

*BONUS / OPTIONAL SIDE QUESTS*

These are independent extensions. The seven-part case has an IMU cradle; it has no designed mounting for the speaker, amplifier, or distance sensor.

### Motion and distance for the looper

| Module | Connections / expected I2C address |
| --- | --- |
| MPU6050 / GY-521 | 3.3 V-compatible VCC; GND; SDA -> GPIO12; SCL -> GPIO13. AD0 low for 0x68; verify board default. |
| VL53L0X breakout | Verified 3.3 V-compatible supply and I2C; GND; SDA -> GPIO12; SCL -> GPIO13. Address 0x29. Leave XSHUT/INT at the module's documented defaults. |

These share the OLED's I2C wires. Check breakout supply requirements and pull-ups before connecting; pull-ups must go to 3V3. If none of the boards provide them, add one 4.7 kOhm pull-up from SDA to 3V3 and one from SCL to 3V3. Do not add a new pair blindly to every board.

Use tools/app.sh looper, then flash, to try motion and distance expression. The driver implements VL53L0X, not VL53L1X. An I2C scan finds presence; testing tilt/distance in the looper verifies actual behavior.

### MAX98357A speaker branch: bench extension

| Amplifier pin | Connection |
| --- | --- |
| BCLK / LRC / DIN | GPIO7 / GPIO8 / GPIO9 (shared with the DAC) |
| SD / GND / GAIN | GPIO11 / common GND / floating, if supported by your board |
| VIN | Verified regulated supply with enough current for the speaker load |
| Speaker + and - | A suitable 4 or 8 ohm speaker across the two outputs |

> **SPEAKER OUTPUT IS NOT GROUND**
>
> Neither speaker terminal goes to GND or to the DAC jack. Do not load the SuperMini's small 3V3 regulator with the amp. For a separate rated amp supply, join grounds but do not tie its positive rail to USB 5V without a designed power path.

Current firmware enables the amp while the GPIO6 encoder switch is held, unless Kit firmware > Keep the speaker amp on all the time is enabled. BOOT's software button alias does not enable this hardware gate. The PCM5102A line-out is independent of that gate. Speaker power distribution and mounting need separate validation before boxing this extension.

## 15. One clue at a time.

*RESCUE / EVERY BUILD HAS A PLOT TWIST*

Unplug before touching wiring. Return to the hardware-test app for diagnosis; reconnect one stage at a time.

| What you see or hear | Try this first |
| --- | --- |
| No serial device / flashing fails | Try a known data cable and direct USB port; close other serial monitors. Enter BOOT download mode (page 5). Check port permissions. |
| Screen dark; firmware running | Check OLED VCC/GND, then GPIO12 SDA and GPIO13 SCL. Look for 0x3C. Test app can retry 0x3D; JAM expects 0x3C. |
| Tone missing; screen works | Check external AUX/line input and volume. Unplug; check DAC VIN, BCK=7, LCK=8, DIN=9, SCK=GND and XSMT=H. |
| Tone works; mic silent | Check INMP441 VDD=3V3, SD=10, SCK=7, WS=8 and L/R tied low. Read the test diagnosis; inspect for a blocked mic port. |
| RIGHT slot message | Mic L/R is high. Supported by the firmware; not a fault if the level meter responds. |
| Intermittent / line stuck | Inspect fitted headers, shared grounds and loose jumpers. Reconnect with power off. Keep signal wiring short. |
| Repeated boots / BROWNOUT | Disconnect USB immediately if anything gets hot. Remove the newest module; check shorts, polarity, cable and power budget. Retry the known-good stage. |
| Encoder reversed / skips | Verify common=GND and A/B=4/5. Exchange A/B if reversed. For multiple steps per detent, check Kit firmware > Encoder counts per detent. |
| Joystick odd / no click | Reboot with stick centered. Check VRy=1, VRx=2, SW=3 and 3V3 power. Firmware rotation is intentional for the case. |
| Squeal / distortion | Lower listening volume; move speaker away from mic. Check input mode and mic gain. Do not use the DAC to drive passive speakers or headphones directly. |
| Line-out works; optional speaker silent | Check amp supply and SD=11. It is normally enabled only while GPIO6 is held; see page 14. |
| Works open, fails closed | Unplug and reopen. Look for a pinched wire, a loose connector, screw contact, blocked mic port, or knob pressed against the panel. |

> **ASK FOR HELP WITH A GOOD CLUE**
>
> Share clear photos of both sides of each board, your GPIO-to-label wiring list, firmware application, and the relevant serial log. Include the exact module revision and what passed before the failure.

## 16. Your pocket pin map.

*WORKBENCH CARD / KEEP THIS PAGE HANDY*

Signal labels, not physical pin order. Unplug before changing connections. Firmware source of truth: firmware/main/pins.h.

| ESP32 | Destination |
| --- | --- |
| GPIO1 / GPIO2 / GPIO3 | Joystick VRy / VRx / SW |
| GPIO4 / GPIO5 / GPIO6 | Encoder A / B / push switch; common and other switch contact -> GND |
| GPIO7 | Mic SCK + DAC BCK (+ optional amp BCLK) |
| GPIO8 | Mic WS + DAC LCK (+ optional amp LRC) |
| GPIO9 | DAC DIN (+ optional amp DIN) |
| GPIO10 | Mic SD |
| GPIO11 | Optional amp SD |
| GPIO12 / GPIO13 | OLED + optional sensors SDA / SCL |
| 3V3 / GND | Verified 3.3 V modules / all module grounds |
| Verified USB 5V rail | VIN of verified regulator-equipped purple DAC only |

> **THE EASY-TO-MISS CONNECTIONS**
>
> Mic L/R -> GND. DAC SCK -> GND. Purple DAC straps: FLT=L, DEMP=L, XSMT=H, FMT=L (confirm your revision). Never put 5 V on GPIO. Leave USB GPIO19/20 and other boot/strapping pins alone.

### A few words decoded

GPIO: a programmable signal pin. DAC: digital sound to analog audio. I2S: digital audio bus. I2C: two-wire display/sensor bus. VIN/VCC/VDD: power labels whose voltage depends on the board. Continuity: a meter check for an electrical connection. Dry-fit: assemble without power or permanent fastening.

### Sources and build notes

Prepared from the repository's firmware/main/pins.h, main.c, app_test.c, audio.c, input.c and Kconfig.projbuild, README.md, parts/minimal-kit.md and enclosure/. This guide documents the prototype; no physical assembly or electrical test was performed for this edition.

- [Project and firmware](https://github.com/willbearfruits/esp32-s3-supermini-kit)
- [Releases with ready-to-flash images](https://github.com/willbearfruits/esp32-s3-supermini-kit/releases)
- [esptool-js browser flasher](https://espressif.github.io/esptool-js/)
- [Espressif: install ESP-IDF v5.5 for ESP32-S3](https://docs.espressif.com/projects/esp-idf/en/v5.5/esp32s3/get-started/index.html)
- [TI: PCM5102A line-output specification](https://www.ti.com/product/PCM5102A)
- [Adafruit: MAX98357A breakout pinouts (match your board)](https://learn.adafruit.com/adafruit-max98357-i2s-class-d-mono-amp/pinouts)

Illustrations are editable SVGs with PNG companions; case and JAM images come from this repository. Documentation and artwork: MIT, as in the repository license.

## Rebuild the guide

The content lives in `guide.json`; the builder creates all illustrations and formats from it. Requires Python 3.10+, Cairo, and Liberation Sans/Mono fonts (or set `KIT_GUIDE_FONT_DIR` to a directory containing the matching TTF files).

```sh
python3 -m venv /tmp/kit-guide-venv
/tmp/kit-guide-venv/bin/pip install -r docs/assembly/requirements.txt
/tmp/kit-guide-venv/bin/python tools/build-assembly-guide.py
```

The PDF goes to `output/pdf/`. The builder checks the documented GPIO map against `firmware/main/pins.h` and fails on overflowing PDF pages. After edits, render the PDF with `pdftoppm` and visually inspect all pages. Check hardware-specific statements again if firmware or enclosure geometry changes.

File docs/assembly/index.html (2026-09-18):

SUPERMINI / BUILD & PLAYDownload the 16-page PDF

LET'S BUILD A MUSIC MACHINE

# Make a little noise.

A microphone, a tiny screen, two playful controls, and a whole lot of sound. Build your kit one small win at a time.

Illustrated layout of the current case. USB-C and line-out exit the front edge.

Illustrated layout of the current case. USB-C and line-out exit the front edge.

YOUR FINISH LINE

A USB-powered instrument that hears your voice and plays through powered speakers, an audio interface, or a separate headphone amp.

This is a guide to the current wired prototype. The socketed carrier PCB is not finished. Some parts need soldered headers or prepared leads, and the printed case must be checked against your exact boards.

Follow the numbered missions, tick the checkpoints, and keep the case open until the electronics pass. First electronics build? Invite an experienced maker for the soldering and power checks.

Inside: a parts field guide, labeled wiring diagrams, firmware steps, case assembly, a first-beat challenge, and a rescue page. All wiring illustrations use signal names, not physical pin positions.

00 / CHOOSE YOUR ADVENTURE

## Small steps. Happy beeps.

Work on a clear, nonconductive table. Give yourself an unhurried afternoon for the electronics, plus printing and software setup time.

Mission | Your small win | Page
Prepare | Identify every module and power pin | 3-4
Wake up the brain | Flash the hardware-test app | 5
Add the senses | Screen on; mic responding | 6-7
Make sound | Wire the DAC and controls; pass the bench test | 8-10
Give it a home | Dry-fit, mount, route, close | 11-12
Play | Make a beat in JAM | 13

### Put these within reach

- A computer, USB-C data cable, and powered speaker with AUX/line input (or an audio interface / headphone amplifier). A charge-only cable cannot flash the board.
- Short jumper wires with ends that fit your headers; a breadboard or insulated distribution board for shared connections. Check whether breadboard power rails are split.
- A multimeter, small screwdrivers, tape labels, wire cutters, and a ruler or calipers. Use insulated wire and strain relief for the final harness.
- For unfinished headers, DAC straps, or the bare EC11: a soldering iron, stand, solder, ventilation, and heat-shrink. Get hands-on help if these are new to you.

THE ONE HABIT THAT SAVES BOARDS

Unplug USB and every other power source before adding, moving, soldering, or checking continuity on a wire. Power up only after checking the new connections.

Solderless means the connections are already prepared: headers fitted, DAC straps set, and the encoder on an adapter or harness. Loose pins pushed through bare holes are not reliable electrical joints.

Checkpoint I have a data cable and a suitable line-level listening device. I know which parts need soldering or prepared leads.

01 / MEET THE BAND

## Seven little teammates.

Match the printed labels and the exact board version. Color and shape are clues, never proof of a pinout.

Simplified identification drawings; not to scale and not a footprint or pin-order reference.

Simplified identification drawings; not to scale and not a footprint or pin-order reference.

Qty | Part | Check before wiring
1 | ESP32-S3 SuperMini | ESP32-S3FH4R2; 4 MB flash, 2 MB PSRAM; USB-C
1 | PCM5102A DAC | Purple jack board; verify VIN rating and all four straps
1 | KY-023-style joystick | Board with fitted pins and cap; VRx, VRy, SW
1 | Bare EC11 encoder | Push switch, matching nut/washer/knob; prepared leads
1 | INMP441 microphone | Round six-pin board; confirm actual chip and pin labels
1 | SSD1306 OLED | 0.96-inch, 128 x 64, four-pin I2C version
1 | MPU6050 / GY-521 | Motion sensor; optional for first sound and JAM

Also gather wiring, the USB data cable, and a line-out cable. Case hardware is listed on page 11. The MAX98357A speaker amp and VL53L0X distance sensor are optional extras (page 14), not part of this seven-part list.

LOOK TWICE, PLUG ONCE

Some OLEDs swap VCC and GND. Some six-pin microphones use another chip. Seller listings are not verified kit specifications. If a pin or board revision is unclear, identify it before powering it.

Checkpoint My modules match this list, and their power pins are readable.

02 / POWER WITHOUT SURPRISES

## Two rails. One ground.

A rail is a shared power connection. GND is the common reference. GPIO numbers identify signals on the ESP32, not the position of a header pin.

USB powers the ESP32. Use its labeled rails only after checking your board's power path.

USB powers the ESP32. Use its labeled rails only after checking your board's power path.

- Use USB-only power for this build. Identify the SuperMini's labeled 3V3, GND, and USB 5V/VBUS pins from the exact board documentation. Do not count header positions from a generic photo.
- Use 3.3 V for the INMP441, joystick, and a verified 3.3 V-compatible OLED. Sensor add-ons must also keep SDA/SCL and all GPIO signals at 3.3 V.
- The documented purple DAC board uses 5 V at VIN through its onboard regulator. Confirm this for your revision before connecting it. Never put 5 V on a bare PCM5102A chip, a 3V3 pin, or an ESP32 GPIO.
- Join every module GND to ESP32 GND. Make shared connections with proper rails or a soldered distribution point; do not cram several wires into one jumper socket.

UNPLUGGED CHECK

Check polarity and continuity of each intended ground connection. Check that 3V3-to-GND and 5V-to-GND are not sustained near-zero-ohm shorts. A brief continuity beep from charging capacitors is not a diagnosis; investigate uncertain readings before power-up.

Leave batteries and charging boards out of this build: the project has no completed battery power-path design. Add only one module per mission, with USB disconnected between changes.

Checkpoint I can point to 3V3, GND, and the verified USB 5V rail. The DAC VIN rating is confirmed, and no GPIO wire carries 5 V.

03 / WAKE UP THE BRAIN

## Teach it the test tune.

Start with only the ESP32 connected to USB. The hardware-test app lets you add modules gradually and see what is working.

The quickest route needs no toolchain: every release on GitHub ships one file per application that flashes at offset 0. Download kit-test.bin from the latest release, install esptool with pip, and write it. Use the port your system shows: /dev/ttyACM0 on Linux, /dev/cu.usbmodem* on macOS, COM3 or similar on Windows.

pip install esptool
esptool.py --chip esp32s3 write_flash 0x0 kit-test.bin

No terminal? Open esptool-js (linked on page 16) in Chrome or Edge, connect, pick kit-test.bin at address 0x0, and program. Building from source instead: install ESP-IDF v5.5 with ESP32-S3 support, then run tools/app.sh test in the repository and idf.py flash monitor in firmware/. The build fetches components from the internet the first time.

To watch the serial log without ESP-IDF, use any terminal at 115200 baud on the same port. The log names the likely missing wire when something is off. Exit idf.py monitor with Ctrl+].

A SUCCESSFUL FIRST BOOT

Look for the test-app message about a 440 Hz tone for 4 seconds, then mic only. No OLED and no mic data are expected right now. Unplug USB before attaching the display.

Board missing? Try another data cable and USB port; a charge-only cable never shows up. To enter download mode, hold BOOT, tap RESET, then release BOOT and flash again. If your board lacks RESET, hold BOOT while reconnecting USB, then release it. On Linux, follow Espressif's serial-port permissions instructions if access is denied.

Checkpoint The hardware-test firmware flashes and its serial log appears.

04 / GIVE IT A FACE

## Hello, tiny screen.

Disconnect USB. Read the four OLED labels carefully; their order varies between modules.

Functional connections only. SCL may be printed SCK on an I2C OLED; check the module type.

Functional connections only. SCL may be printed SCK on an I2C OLED; check the module type.

OLED label | Connect to
VCC / VDD | ESP32 3V3, for a verified 3.3 V-compatible module
GND | ESP32 GND
SDA | GPIO12
SCL | GPIO13

Reconnect USB. The serial scan should report 0x3C and the screen should show the test display. The hardware-test app also retries at 0x3D; the main startup path and JAM expect 0x3C. Use a module configured for 0x3C for the finished build.

SCREEN STILL DARK?

Unplug first. Check VCC/GND, then SDA/SCL, then the module's I2C address. A seven-pin SPI display or an SH1106 board is not the specified SSD1306 module. If the image is upside down, Kit firmware > Rotate the OLED 180 degrees controls its orientation.

I2C is a shared two-wire conversation: SDA carries data and SCL keeps time. Later sensors can share these same two signals. The audio wires on the next pages use a different bus called I2S.

Checkpoint The screen lights up and the test display updates.

05 / GIVE IT EARS

## Say hello. Watch it listen.

Disconnect USB, then add the INMP441. Keep its small sound opening clear of tape, glue, and fingers.

The mic's SCK is the bit clock on GPIO7. Its SD is data going into GPIO10.

The mic's SCK is the bit clock on GPIO7. Its SD is data going into GPIO10.

INMP441 label | Connect to
VDD | 3V3
GND | GND
SCK | GPIO7
WS | GPIO8
SD | GPIO10
L/R | GND for this guide; do not leave floating

Reconnect USB. Wait for the four-second test-tone interval to finish, then speak or hum near the microphone. The level bar and waveform should respond. The serial diagnosis should settle on mic data OK.

TINY VICTORY

The board can hear you even before an audio output is connected. If the firmware reports the RIGHT slot, L/R is high; the firmware supports that too. No data means check mic power, SD, SCK and WS with USB unplugged.

I2S sends sound as numbers. GPIO7 and GPIO8 provide shared timing; the microphone sends its numbers back on GPIO10. The DAC will receive outgoing numbers on a separate wire, GPIO9.

Checkpoint My voice changes the level meter and the mic diagnosis is healthy.

06 / LET THE SOUND OUT

## Meet the purple sound card.

Disconnect USB. The PCM5102A turns digital audio into a stereo line signal for an amplified listening device.

The two SCK labels mean different things: mic SCK -> GPIO7; DAC SCK -> GND.

The two SCK labels mean different things: mic SCK -> GPIO7; DAC SCK -> GND.

DAC label | Connect to
VIN | Verified USB 5V rail, only for the regulator-equipped board
GND | GND
BCK | GPIO7 (shared with mic SCK)
LCK / LRCK | GPIO8 (shared with mic WS)
DIN | GPIO9
SCK | GND; check whether the board already ties it low

Check the back-of-board configuration. For the documented purple revision: H1L / FLT = L, H2L / DEMP = L, H3L / XSMT = H, H4L / FMT = L. Confirm each pad's function on your revision; bridge only the selected side, never H to L. Use a prepared board or get soldering help.

THIS JACK IS LINE-OUT

Connect powered speakers, an audio-interface line input, or a separate headphone amplifier. Ordinary headphones and passive speakers need amplification. TI specifies line loads down to 1 kOhm; a headphone-shaped jack does not make this a headphone amp.

Start the listening device at low volume. Connect its line/AUX input, then power the kit. Listen for the four-second 440 Hz tone. After it ends, try a gentle hum; keep the speaker away from the mic to avoid feedback.

Checkpoint I hear the startup tone and can hear the mic afterward.

07 / ADD THE PLAYFUL BITS

## Twist. Tilt. Click.

Disconnect USB. The joystick uses a breakout board; the bare EC11 needs an identified pinout and a soldered adapter or insulated harness.

Logical EC11 contacts are shown, not their physical order. Mounting tabs are not signal pins.

Logical EC11 contacts are shown, not their physical order. Mounting tabs are not signal pins.

Control contact | Connect to
Joystick VCC / +5V marking | 3V3 for this analog KY-023-style module; never 5 V here
Joystick GND / VRy / VRx / SW | GND / GPIO1 / GPIO2 / GPIO3, respectively
EC11 A / B / common C | GPIO4 / GPIO5 / GND, respectively
EC11 push switch, two contacts | One to GPIO6; the other to GND

Identify encoder A/B/common and the separate push switch from its drawing or an unplugged continuity test. Do not infer the pin order from this illustration. For an encoder breakout instead, map CLK, DT and SW to GPIO4, GPIO5 and GPIO6; power any onboard pull-ups from 3V3.

Power up without touching the joystick so startup centering can work. Turning the encoder brings up the ENCODER test screen and changes its count. A tap changes effect; a half-second hold changes preset. If turning is reversed, unplug and exchange A/B.

SAVE THE JOYSTICK VICTORY FOR JAM

The test app is mainly a mic/DAC/encoder check. Use JAM on page 13 to verify joystick navigation and click. The firmware rotates the joystick axes for the case mounting; do not swap VRx/VRy just to match the drawing's appearance.

Checkpoint Encoder turn and push both work; the joystick is powered from 3V3.

08 / THE OPEN-CASE SOUND CHECK

## Earn your first-sound badge.

Keep everything on the bench. A working open build is much easier to assemble and troubleshoot than a mystery inside a closed box.

Try this | You should get
Restart the test app | A stable boot, then about 4 seconds of 440 Hz tone
Speak gently after the tone | A moving level meter and audible mic signal
Watch the serial diagnosis | mic data OK, or mic OK, RIGHT slot
Turn the encoder | ENCODER page; count changes consistently
Tap, then briefly hold the encoder | Effect changes; then preset changes
Leave the kit running for a few minutes | No repeated boot counter increments, dropouts or excess heat

DO NOT CLOSE THE CASE YET

One failed check is a useful clue. Unplug, inspect that stage, fix it, and repeat the check. The firmware's no shorts between I2S pins message covers only selected signal pairs; it is not a power-rail safety test.

### Label future-you's wires

- Label both ends with the signal name or GPIO number. Color is a helpful extra: use red for 3V3, orange for 5V, and black for GND if you have them.
- Replace flaky temporary connections with fitted headers and insulated, strain-relieved wiring. Keep audio wires short and away from loose metal hardware.
- Photograph your working wiring before moving it into the shell. Leave enough slack to open the case without pulling a connector off.
- If you hear a squeal, lower the external volume and move the speaker away from the mic. This is acoustic feedback, not a challenge to sing louder.

Checkpoint All the checks above pass with the case open. Both ends of each wire are labeled and the wiring is documented. USB is unplugged before I begin mechanical assembly.

09 / MAKE ITS LITTLE HOME

## Print. Measure. Dry-fit.

The current shell is 100 x 98 x 24 mm. Its cradles model specific module sizes; a board with the same chip can still have a different outline.

Existing OpenSCAD exploded render from this repository. CAD preview, not proof of physical fit.

Existing OpenSCAD exploded render from this repository. CAD preview, not proof of physical fit.

Use enclosure/out/shell.stl and lid.stl, or the combined print_bed.stl. The exports are already print-oriented: shell top face down, lid bottom face down. Inspect the sliced layers and small bosses before printing.

The design targets a 0.8 mm nozzle, 2.4 mm walls, and 0.32-0.40 mm layers. Start with 3 walls and enough solid layers for 2.4 mm thickness (6 at 0.40 mm or 8 at 0.32 mm), plus 20-30% infill. The CAD intends support-free printing; confirm in your slicer.

Case hardware | Quantity / starting specification
Heat-set inserts + lid screws | 4 M3 inserts (OD about 4.6 mm, length 4-5.7 mm); 4 M3 x 10 mm screws
OLED / joystick screws | 4 M2 x 4 mm / 4 M2 x 6 mm; verify actual engagement
Encoder hardware | Matching M7 nut/washer and 6 mm shaft knob
Mic gasket + wire restraint | One foam/silicone ring; small ties or insulated restraint

FIT FIRST, HEAT SECOND

Try every unpowered board in its cradle, including headers, plug bodies and wire bends. Fit may require CAD changes. Install inserts in the empty shell using your insert/filament supplier's method; practice on scrap and let them cool. Check screw length so tips cannot bottom out, pierce plastic, or hit a board.

Checkpoint The dry-fit works and every screw is the right length.

10 / EVERY PART GETS A PLACE

## Build the shell sandwich.

USB stays unplugged. Use the drawing as a placement key, then follow the actual mounting features in your printed parts.

Conceptual top-view placement, not a drill template. Both panels use the same front-edge reference.

Conceptual top-view placement, not a drill template. Both panels use the same front-edge reference.

1. Top shell: fasten the OLED behind its window with four M2 screws. Use light pressure; do not load or pinch the glass.
2. Seat the round mic beside the OLED with its real acoustic port aligned to the grille. Place the gasket around the port; do not cover the opening or force the PCB into the collar.
3. Fit the EC11 through its panel opening, secure the matching washer/nut, and add the knob. Keep enough clearance for the push action. Mount the joystick on its four bosses and check full travel.
4. Lid: seat the ESP32 with USB-C at the front edge. Seat the DAC on the right with its jack facing that same front edge, beside USB. Secure the optional IMU in its own cradle if fitted.
5. Reconnect the labeled harness. Insulate exposed joints, restrain wires, and keep the seam, screw bosses, antenna area and mic port clear. Check connector and pin clearance with the halves gently together.
6. With the case still open on a nonconductive surface, repeat the page 10 sound check. Unplug, align the lip, and close with four lid screws, lightly and evenly. If it resists, reopen and find the obstruction.

Checkpoint No wire is pinched; USB/audio plugs seat fully; the knob clicks and stick moves. After closing, the screen, startup tone, microphone and encoder still work.

11 / MAKE YOUR FIRST BEAT

## Your tiny band is ready.

Switch to JAM when the hardware checks pass. It is the case-friendly sequencer: six channels, a sampler, and a grid of musical possibilities.

Actual JAM drum-grid render from the repository. The grid contains two bars of 16 steps.

Actual JAM drum-grid render from the repository. The grid contains two bars of 16 steps.

Flash kit-jam.bin from the release the same way as the test image, or from source: tools/app.sh jam in the repository, then idf.py flash in firmware/. JAM is the default application when building from a fresh checkout.

esptool.py --chip esp32s3 write_flash 0x0 kit-jam.bin

Gesture in JAM | What happens
Turn encoder / flick joystick | Move the pattern cursor
Tap encoder | Toggle the selected grid cell
Hold encoder about 0.5 seconds | Next page: PATTERN, MIX, SONG, SETUP
Push encoder and turn | Change channel
Click joystick | Enter/cycle perform mode; behavior depends on channel
Hold encoder 3 seconds | Clear the current channel - use deliberately

THE FIRST-BEAT CHALLENGE

Select DRUMS on PATTERN. Put kicks on steps 1, 5, 9 and 13 of the first bar; add snare on 5 and 13 and hats on odd steps. Repeat in the second bar. Then switch to BASS and add three notes. Hear that? You built the band.

Verify the joystick moves the cursor and its click changes perform mode. JAM autosaves about two seconds after the last edit; wait a few extra seconds before unplugging. Try a sample next: select MIC and tap to record up to two seconds, then select SAMPLE. Live mic is audible only while MIC is selected.

Checkpoint My beat plays, the joystick works, and my pattern returns after a restart.

BONUS / OPTIONAL SIDE QUESTS

## Add extras after the win.

These are independent extensions. The seven-part case has an IMU cradle; it has no designed mounting for the speaker, amplifier, or distance sensor.

### Motion and distance for the looper

Module | Connections / expected I2C address
MPU6050 / GY-521 | 3.3 V-compatible VCC; GND; SDA -> GPIO12; SCL -> GPIO13. AD0 low for 0x68; verify board default.
VL53L0X breakout | Verified 3.3 V-compatible supply and I2C; GND; SDA -> GPIO12; SCL -> GPIO13. Address 0x29. Leave XSHUT/INT at the module's documented defaults.

These share the OLED's I2C wires. Check breakout supply requirements and pull-ups before connecting; pull-ups must go to 3V3. If none of the boards provide them, add one 4.7 kOhm pull-up from SDA to 3V3 and one from SCL to 3V3. Do not add a new pair blindly to every board.

Use tools/app.sh looper, then flash, to try motion and distance expression. The driver implements VL53L0X, not VL53L1X. An I2C scan finds presence; testing tilt/distance in the looper verifies actual behavior.

### MAX98357A speaker branch: bench extension

Amplifier pin | Connection
BCLK / LRC / DIN | GPIO7 / GPIO8 / GPIO9 (shared with the DAC)
SD / GND / GAIN | GPIO11 / common GND / floating, if supported by your board
VIN | Verified regulated supply with enough current for the speaker load
Speaker + and - | A suitable 4 or 8 ohm speaker across the two outputs

SPEAKER OUTPUT IS NOT GROUND

Neither speaker terminal goes to GND or to the DAC jack. Do not load the SuperMini's small 3V3 regulator with the amp. For a separate rated amp supply, join grounds but do not tie its positive rail to USB 5V without a designed power path.

Current firmware enables the amp while the GPIO6 encoder switch is held, unless Kit firmware > Keep the speaker amp on all the time is enabled. BOOT's software button alias does not enable this hardware gate. The PCM5102A line-out is independent of that gate. Speaker power distribution and mounting need separate validation before boxing this extension.

RESCUE / EVERY BUILD HAS A PLOT TWIST

## One clue at a time.

Unplug before touching wiring. Return to the hardware-test app for diagnosis; reconnect one stage at a time.

What you see or hear | Try this first
No serial device / flashing fails | Try a known data cable and direct USB port; close other serial monitors. Enter BOOT download mode (page 5). Check port permissions.
Screen dark; firmware running | Check OLED VCC/GND, then GPIO12 SDA and GPIO13 SCL. Look for 0x3C. Test app can retry 0x3D; JAM expects 0x3C.
Tone missing; screen works | Check external AUX/line input and volume. Unplug; check DAC VIN, BCK=7, LCK=8, DIN=9, SCK=GND and XSMT=H.
Tone works; mic silent | Check INMP441 VDD=3V3, SD=10, SCK=7, WS=8 and L/R tied low. Read the test diagnosis; inspect for a blocked mic port.
RIGHT slot message | Mic L/R is high. Supported by the firmware; not a fault if the level meter responds.
Intermittent / line stuck | Inspect fitted headers, shared grounds and loose jumpers. Reconnect with power off. Keep signal wiring short.
Repeated boots / BROWNOUT | Disconnect USB immediately if anything gets hot. Remove the newest module; check shorts, polarity, cable and power budget. Retry the known-good stage.
Encoder reversed / skips | Verify common=GND and A/B=4/5. Exchange A/B if reversed. For multiple steps per detent, check Kit firmware > Encoder counts per detent.
Joystick odd / no click | Reboot with stick centered. Check VRy=1, VRx=2, SW=3 and 3V3 power. Firmware rotation is intentional for the case.
Squeal / distortion | Lower listening volume; move speaker away from mic. Check input mode and mic gain. Do not use the DAC to drive passive speakers or headphones directly.
Line-out works; optional speaker silent | Check amp supply and SD=11. It is normally enabled only while GPIO6 is held; see page 14.
Works open, fails closed | Unplug and reopen. Look for a pinched wire, a loose connector, screw contact, blocked mic port, or knob pressed against the panel.

ASK FOR HELP WITH A GOOD CLUE

Share clear photos of both sides of each board, your GPIO-to-label wiring list, firmware application, and the relevant serial log. Include the exact module revision and what passed before the failure.

WORKBENCH CARD / KEEP THIS PAGE HANDY

## Your pocket pin map.

Signal labels, not physical pin order. Unplug before changing connections. Firmware source of truth: firmware/main/pins.h.

ESP32 | Destination
GPIO1 / GPIO2 / GPIO3 | Joystick VRy / VRx / SW
GPIO4 / GPIO5 / GPIO6 | Encoder A / B / push switch; common and other switch contact -> GND
GPIO7 | Mic SCK + DAC BCK (+ optional amp BCLK)
GPIO8 | Mic WS + DAC LCK (+ optional amp LRC)
GPIO9 | DAC DIN (+ optional amp DIN)
GPIO10 | Mic SD
GPIO11 | Optional amp SD
GPIO12 / GPIO13 | OLED + optional sensors SDA / SCL
3V3 / GND | Verified 3.3 V modules / all module grounds
Verified USB 5V rail | VIN of verified regulator-equipped purple DAC only

THE EASY-TO-MISS CONNECTIONS

Mic L/R -> GND. DAC SCK -> GND. Purple DAC straps: FLT=L, DEMP=L, XSMT=H, FMT=L (confirm your revision). Never put 5 V on GPIO. Leave USB GPIO19/20 and other boot/strapping pins alone.

### A few words decoded

GPIO: a programmable signal pin. DAC: digital sound to analog audio. I2S: digital audio bus. I2C: two-wire display/sensor bus. VIN/VCC/VDD: power labels whose voltage depends on the board. Continuity: a meter check for an electrical connection. Dry-fit: assemble without power or permanent fastening.

### Sources and build notes

Prepared from the repository's firmware/main/pins.h, main.c, app_test.c, audio.c, input.c and Kconfig.projbuild, README.md, parts/minimal-kit.md and enclosure/. This guide documents the prototype; no physical assembly or electrical test was performed for this edition.

- Project and firmware (https://github.com/willbearfruits/esp32-s3-supermini-kit)
- Releases with ready-to-flash images (https://github.com/willbearfruits/esp32-s3-supermini-kit/releases)
- esptool-js browser flasher (https://espressif.github.io/esptool-js/)
- Espressif: install ESP-IDF v5.5 for ESP32-S3 (https://docs.espressif.com/projects/esp-idf/en/v5.5/esp32s3/get-started/index.html)
- TI: PCM5102A line-output specification (https://www.ti.com/product/PCM5102A)
- Adafruit: MAX98357A breakout pinouts (match your board) (https://learn.adafruit.com/adafruit-max98357-i2s-class-d-mono-amp/pinouts)

Illustrations are editable SVGs with PNG companions; case and JAM images come from this repository. Documentation and artwork: MIT, as in the repository license.

Prototype edition / September 2026. Checklist stays in this browser when local storage is available.

Reset my checklist

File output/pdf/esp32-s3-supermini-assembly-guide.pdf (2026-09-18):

SUPERMINI / BUILD & PLAY | PROTOTYPE EDITION / SEPT 2026

LET'S BUILD A MUSIC MACHINE
Make a little noise.

A microphone, a tiny screen, two playful controls, and a whole lot of sound. Build your kit one small win at a time.

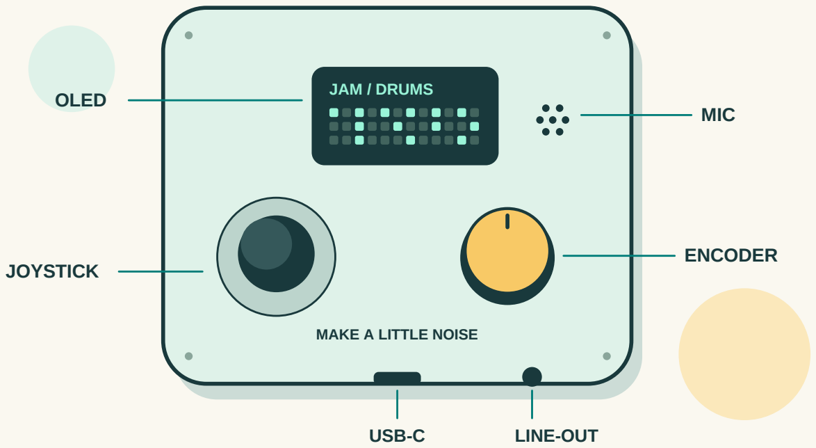
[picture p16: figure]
JAM / DRUMS; MAKE A LITTLE NOISE; OLED; MIC; JOYSTICK; ENCODER; USB-C; LINE-OUT

Illustrated layout of the current case. USB-C and line-out exit the front edge.

YOUR FINISH LINE
A USB-powered instrument that hears your voice and plays through powered speakers, an audio interface, or a separate headphone amp.

This is a guide to the current wired prototype. The socketed carrier PCB is not finished. Some parts need soldered headers or prepared leads, and the printed case must be checked against your exact boards.

Follow the numbered missions, tick the checkpoints, and keep the case open until the electronics pass. First electronics build? Invite an experienced maker for the soldering and power checks.

Inside: a parts field guide, labeled wiring diagrams, firmware steps, case assembly, a first-beat challenge, and a rescue page. All wiring illustrations use signal names, not physical pin positions.

ESP32-S3 SUPERMINI / UNPLUG BEFORE REWIRING | 01 / 16

00 / CHOOSE YOUR ADVENTURE
Small steps. Happy beeps.

Work on a clear, nonconductive table. Give yourself an unhurried afternoon for the electronics, plus printing and software setup time.

Mission | Your small win | Page
Prepare | Identify every module and power pin | 3-4
Wake up the brain | Flash the hardware-test app | 5
Add the senses | Screen on; mic responding | 6-7
Make sound | Wire the DAC and controls; pass the bench test | 8-10
Give it a home | Dry-fit, mount, route, close | 11-12
Play | Make a beat in JAM | 13

Put these within reach

A computer, USB-C data cable, and powered speaker with AUX/line input (or an audio interface / headphone amplifier). A charge-only cable cannot flash the board.

Short jumper wires with ends that fit your headers; a breadboard or insulated distribution board for shared connections. Check whether breadboard power rails are split.

A multimeter, small screwdrivers, tape labels, wire cutters, and a ruler or calipers. Use insulated wire and strain relief for the final harness.

For unfinished headers, DAC straps, or the bare EC11: a soldering iron, stand, solder, ventilation, and heat-shrink. Get hands-on help if these are new to you.

THE ONE HABIT THAT SAVES BOARDS
Unplug USB and every other power source before adding, moving, soldering, or checking continuity on a wire. Power up only after checking the new connections.

Solderless means the connections are already prepared: headers fitted, DAC straps set, and the encoder on an adapter or harness. Loose pins pushed through bare holes are not reliable electrical joints.

I have a data cable and a suitable line-level listening device.

I know which parts need soldering or prepared leads.

01 / MEET THE BAND
Seven little teammates.

Match the printed labels and the exact board version. Color and shape are clues, never proof of a pinout.

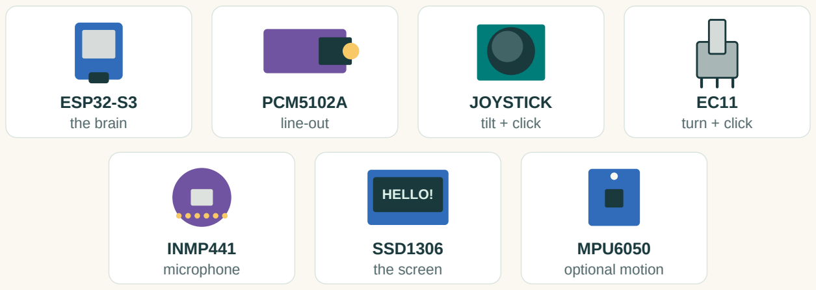
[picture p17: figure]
ESP32-S3; the brain; PCM5102A; line-out; JOYSTICK; tilt + click; turn + click; INMP441; microphone; HELLO!; SSD1306; the screen; MPU6050; optional motion

Simplified identification drawings; not to scale and not a footprint or pin-order reference.

Qty | Part | Check before wiring
1 | ESP32-S3 SuperMini | ESP32-S3FH4R2; 4 MB flash, 2 MB PSRAM; USB-C
1 | PCM5102A DAC | Purple jack board; verify VIN rating and all four straps
1 | KY-023-style joystick | Board with fitted pins and cap; VRx, VRy, SW
1 | Bare EC11 encoder | Push switch, matching nut/washer/knob; prepared leads
1 | INMP441 microphone | Round six-pin board; confirm actual chip and pin labels
1 | SSD1306 OLED | 0.96-inch, 128 x 64, four-pin I2C version
1 | MPU6050 / GY-521 | Motion sensor; optional for first sound and JAM

Also gather wiring, the USB data cable, and a line-out cable. Case hardware is listed on page 11. The MAX98357A speaker amp and VL53L0X distance sensor are optional extras (page 14), not part of this seven-part list.

LOOK TWICE, PLUG ONCE
Some OLEDs swap VCC and GND. Some six-pin microphones use another chip. Seller listings are not verified kit specifications. If a pin or board revision is unclear, identify it before powering it.

My modules match this list, and their power pins are readable.

02 / POWER WITHOUT SURPRISES
Two rails. One ground.

A rail is a shared power connection. GND is the common reference. GPIO numbers identify signals on the ESP32, not the position of a header pin.

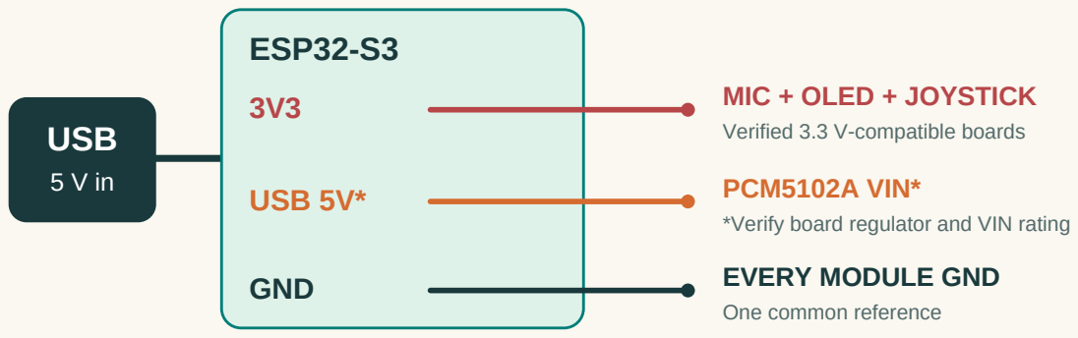
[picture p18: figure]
USB; ESP32-S3; MIC + OLED + JOYSTICK; Verified 3.3 V-compatible boards; USB 5V*; PCM5102A VIN*; *Verify board regulator and VIN rating; GND; EVERY MODULE GND; One common reference

USB powers the ESP32. Use its labeled rails only after checking your board's power path.

Use USB-only power for this build. Identify the SuperMini's labeled 3V3, GND, and USB 5V/VBUS pins from the exact board documentation. Do not count header positions from a generic photo.

Use 3.3 V for the INMP441, joystick, and a verified 3.3 V-compatible OLED. Sensor add-ons must also keep SDA/SCL and all GPIO signals at 3.3 V.

The documented purple DAC board uses 5 V at VIN through its onboard regulator. Confirm this for your revision before connecting it. Never put 5 V on a bare PCM5102A chip, a 3V3 pin, or an ESP32 GPIO.

Join every module GND to ESP32 GND. Make shared connections with proper rails or a soldered distribution point; do not cram several wires into one jumper socket.

UNPLUGGED CHECK
Check polarity and continuity of each intended ground connection. Check that 3V3-to-GND and 5V-to-GND are not sustained near-zero-ohm shorts. A brief continuity beep from charging capacitors is not a diagnosis; investigate uncertain readings before power-up.

Leave batteries and charging boards out of this build: the project has no completed battery power-path design. Add only one module per mission, with USB disconnected between changes.

I can point to 3V3, GND, and the verified USB 5V rail.

The DAC VIN rating is confirmed, and no GPIO wire carries 5 V.

03 / WAKE UP THE BRAIN
Teach it the test tune.

Start with only the ESP32 connected to USB. The hardware-test app lets you add modules gradually and see what is working.

The quickest route needs no toolchain: every release on GitHub ships one file per application that flashes at offset 0. Download kit-test.bin from the latest release, install esptool with pip, and write it. Use the port your system shows: /dev/ttyACM0 on Linux, /dev/cu.usbmodem* on macOS, COM3 or similar on Windows.

pip install esptool

esptool.py --chip esp32s3 write_flash 0x0 kit-test.bin

No terminal? Open esptool-js (linked on page 16) in Chrome or Edge, connect, pick kit-test.bin at address 0x0, and program. Building from source instead: install ESP-IDF v5.5 with ESP32-S3 support, then run tools/app.sh test in the repository and idf.py flash monitor in firmware/. The build fetches components from the internet the first time.

To watch the serial log without ESP-IDF, use any terminal at 115200 baud on the same port. The log names the likely missing wire when something is off. Exit idf.py monitor with Ctrl+].

A SUCCESSFUL FIRST BOOT
Look for the test-app message about a 440 Hz tone for 4 seconds, then mic only. No OLED and no mic data are expected right now. Unplug USB before attaching the display.

Board missing? Try another data cable and USB port; a charge-only cable never shows up. To enter download mode, hold BOOT, tap RESET, then release BOOT and flash again. If your board lacks RESET, hold BOOT while reconnecting USB, then release it. On Linux, follow Espressif's serial-port permissions instructions if access is denied.

The hardware-test firmware flashes and its serial log appears.

04 / GIVE IT A FACE
Hello, tiny screen.

Disconnect USB. Read the four OLED labels carefully; their order varies between modules.

ESP32-S3 / rails | | SSD1306 OLED
3V3 | | VCC / VDD
GND | | GND
GPIO12 | signal: GPIO12 | SDA
GPIO13 | signal: GPIO13 | SCL

Match printed signal labels, not header positions. Unplug USB before rewiring.

Functional connections only. SCL may be printed SCK on an I2C OLED; check the module type.

OLED label | Connect to
VCC / VDD | ESP32 3V3, for a verified 3.3 V-compatible module
GND | ESP32 GND
SDA | GPIO12
SCL | GPIO13

Reconnect USB. The serial scan should report 0x3C and the screen should show the test display. The hardware-test app also retries at 0x3D; the main startup path and JAM expect 0x3C. Use a module configured for 0x3C for the finished build.

SCREEN STILL DARK?
Unplug first. Check VCC/GND, then SDA/SCL, then the module's I2C address. A seven-pin SPI display or an SH1106 board is not the specified SSD1306 module. If the image is upside down, Kit firmware > Rotate the OLED 180 degrees controls its orientation.

I2C is a shared two-wire conversation: SDA carries data and SCL keeps time. Later sensors can share these same two signals. The audio wires on the next pages use a different bus called I2S.

The screen lights up and the test display updates.

05 / GIVE IT EARS
Say hello. Watch it listen.

Disconnect USB, then add the INMP441. Keep its small sound opening clear of tape, glue, and fingers.

ESP32-S3 / rails | | INMP441 mic
3V3 | | VDD
GND | | GND
GPIO7 | signal: GPIO7 | SCK
GPIO8 | signal: GPIO8 | WS
GPIO10 | signal: GPIO10 | SD
GND | | L/R

Match printed signal labels, not header positions. Unplug USB before rewiring.

The mic's SCK is the bit clock on GPIO7. Its SD is data going into GPIO10.

INMP441 label | Connect to
VDD | 3V3
GND | GND
SCK | GPIO7
WS | GPIO8
SD | GPIO10
L/R | GND for this guide; do not leave floating

Reconnect USB. Wait for the four-second test-tone interval to finish, then speak or hum near the microphone. The level bar and waveform should respond. The serial diagnosis should settle on mic data OK.

TINY VICTORY
The board can hear you even before an audio output is connected. If the firmware reports the RIGHT slot, L/R is high; the firmware supports that too. No data means check mic power, SD, SCK and WS with USB unplugged.

I2S sends sound as numbers. GPIO7 and GPIO8 provide shared timing; the microphone sends its numbers back on GPIO10. The DAC will receive outgoing numbers on a separate wire, GPIO9.

My voice changes the level meter and the mic diagnosis is healthy.

06 / LET THE SOUND OUT
Meet the purple sound card.

Disconnect USB. The PCM5102A turns digital audio into a stereo line signal for an amplified listening device.

ESP32-S3 / rails | | PCM5102A DAC
USB 5V* | | VIN*
GND | | GND
GPIO7 | signal: GPIO7 | BCK
GPIO8 | signal: GPIO8 | LCK / LRCK
GPIO9 | signal: GPIO9 | DIN
GND | | SCK

*VIN: verified 5V regulator-equipped board only. Match labels, not pin positions.

The two SCK labels mean different things: mic SCK -> GPIO7; DAC SCK -> GND.

DAC label | Connect to
VIN | Verified USB 5V rail, only for the regulator-equipped board
GND | GND
BCK | GPIO7 (shared with mic SCK)
LCK / LRCK | GPIO8 (shared with mic WS)
DIN | GPIO9
SCK | GND; check whether the board already ties it low

Check the back-of-board configuration. For the documented purple revision: H1L / FLT = L, H2L / DEMP = L, H3L / XSMT = H, H4L / FMT = L. Confirm each pad's function on your revision; bridge only the selected side, never H to L. Use a prepared board or get soldering help.

THIS JACK IS LINE-OUT
Connect powered speakers, an audio-interface line input, or a separate headphone amplifier. Ordinary headphones and passive speakers need amplification. TI specifies line loads down to 1 kOhm; a headphone-shaped jack does not make this a headphone amp.

Start the listening device at low volume. Connect its line/AUX input, then power the kit. Listen for the four-second 440 Hz tone. After it ends, try a gentle hum; keep the speaker away from the mic to avoid feedback.

I hear the startup tone and can hear the mic afterward.

07 / ADD THE PLAYFUL BITS
Twist. Tilt. Click.

Disconnect USB. The joystick uses a breakout board; the bare EC11 needs an identified pinout and a soldered adapter or insulated harness.

JOYSTICK BREAKOUT

VCC | 3V3
GND | GND
VRy | GPIO1
VRx | GPIO2
SW | GPIO3

BARE EC11 CONTACTS

A GPIO4

B GPIO5

Common C | GND
Push contact 1 | GPIO6
Push contact 2 | GND

Logical contacts, not physical pin order. Confirm your EC11 pinout before soldering.

Logical EC11 contacts are shown, not their physical order. Mounting tabs are not signal pins.

Control contact | Connect to
Joystick VCC / +5V marking | 3V3 for this analog KY-023-style module; never 5 V here
Joystick GND / VRy / VRx / SW | GND / GPIO1 / GPIO2 / GPIO3, respectively
EC11 A / B / common C | GPIO4 / GPIO5 / GND, respectively
EC11 push switch, two contacts | One to GPIO6; the other to GND

Identify encoder A/B/common and the separate push switch from its drawing or an unplugged continuity test. Do not infer the pin order from this illustration. For an encoder breakout instead, map CLK, DT and SW to GPIO4, GPIO5 and GPIO6; power any onboard pull-ups from 3V3.

Power up without touching the joystick so startup centering can work. Turning the encoder brings up the ENCODER test screen and changes its count. A tap changes effect; a half-second hold changes preset. If turning is reversed, unplug and exchange A/B.

SAVE THE JOYSTICK VICTORY FOR JAM
The test app is mainly a mic/DAC/encoder check. Use JAM on page 13 to verify joystick navigation and click. The firmware rotates the joystick axes for the case mounting; do not swap VRx/VRy just to match the drawing's appearance.

Encoder turn and push both work; the joystick is powered from 3V3.

08 / THE OPEN-CASE SOUND CHECK
Earn your first-sound badge.

Keep everything on the bench. A working open build is much easier to assemble and troubleshoot than a mystery inside a closed box.

Try this | You should get
Restart the test app | A stable boot, then about 4 seconds of 440 Hz tone
Speak gently after the tone | A moving level meter and audible mic signal
Watch the serial diagnosis | mic data OK, or mic OK, RIGHT slot
Turn the encoder | ENCODER page; count changes consistently
Tap, then briefly hold the encoder | Effect changes; then preset changes
Leave the kit running for a few minutes | No repeated boot counter increments, dropouts or excess heat

DO NOT CLOSE THE CASE YET
One failed check is a useful clue. Unplug, inspect that stage, fix it, and repeat the check. The firmware's no shorts between I2S pins message covers only selected signal pairs; it is not a power-rail safety test.

Label future-you's wires

Label both ends with the signal name or GPIO number. Color is a helpful extra: use red for 3V3, orange for 5V, and black for GND if you have them.

Replace flaky temporary connections with fitted headers and insulated, strain-relieved wiring. Keep audio wires short and away from loose metal hardware.

Photograph your working wiring before moving it into the shell. Leave enough slack to open the case without pulling a connector off.

If you hear a squeal, lower the external volume and move the speaker away from the mic. This is acoustic feedback, not a challenge to sing louder.

All the checks above pass with the case open.

Both ends of each wire are labeled and the wiring is documented.

USB is unplugged before I begin mechanical assembly.

09 / MAKE ITS LITTLE HOME
Print. Measure. Dry-fit.

The current shell is 100 x 98 x 24 mm. Its cradles model specific module sizes; a board with the same chip can still have a different outline.

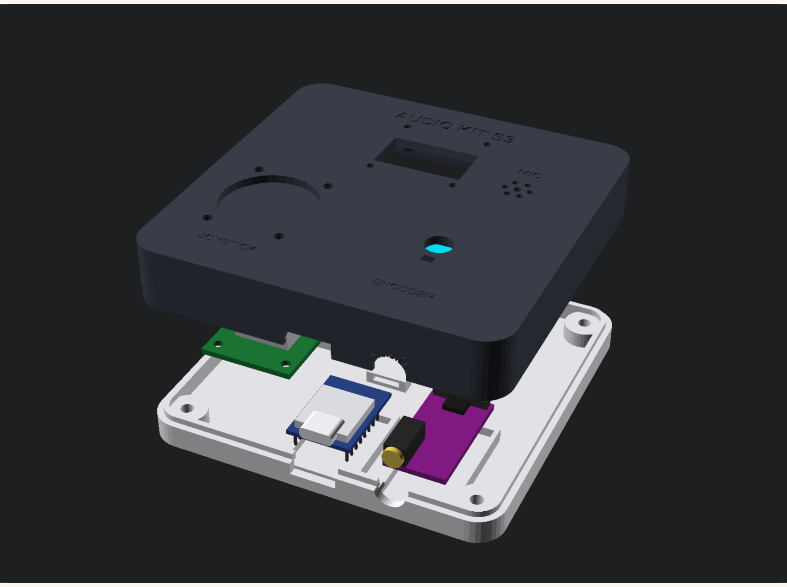
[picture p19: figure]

Existing OpenSCAD exploded render from this repository. CAD preview, not proof of physical fit.

Use enclosure/out/shell.stl and lid.stl, or the combined print_bed.stl. The exports are already print-oriented: shell top face down, lid bottom face down. Inspect the sliced layers and small bosses before printing.

The design targets a 0.8 mm nozzle, 2.4 mm walls, and 0.32-0.40 mm layers. Start with 3 walls and enough solid layers for 2.4 mm thickness (6 at 0.40 mm or 8 at 0.32 mm), plus 20-30% infill. The CAD intends support-free printing; confirm in your slicer.

Case hardware | Quantity / starting specification
Heat-set inserts + lid screws | 4 M3 inserts (OD about 4.6 mm, length 4-5.7 mm); 4 M3 x 10 mm screws
OLED / joystick screws | 4 M2 x 4 mm / 4 M2 x 6 mm; verify actual engagement
Encoder hardware | Matching M7 nut/washer and 6 mm shaft knob
Mic gasket + wire restraint | One foam/silicone ring; small ties or insulated restraint

FIT FIRST, HEAT SECOND
Try every unpowered board in its cradle, including headers, plug bodies and wire bends. Fit may require CAD changes. Install inserts in the empty shell using your insert/filament supplier's method; practice on scrap and let them cool. Check screw length so tips cannot bottom out, pierce plastic, or hit a board.

The dry-fit works and every screw is the right length.

10 / EVERY PART GETS A PLACE
Build the shell sandwich.

USB stays unplugged. Use the drawing as a placement key, then follow the actual mounting features in your printed parts.

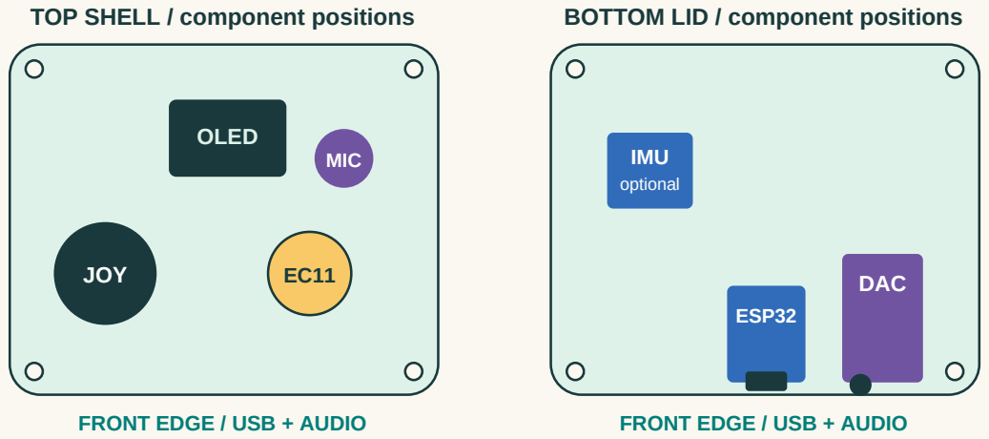
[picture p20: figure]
TOP SHELL / component positions; FRONT EDGE / USB + AUDIO; BOTTOM LID / component positions; OLED; MIC; JOY; IMU; optional; ESP32; DAC

Conceptual top-view placement, not a drill template. Both panels use the same front-edge reference.

1 Top shell: fasten the OLED behind its window with four M2 screws. Use light pressure; do not load or pinch the glass.

2 Seat the round mic beside the OLED with its real acoustic port aligned to the grille. Place the gasket around the port; do not cover the opening or force the PCB into the collar.

3 Fit the EC11 through its panel opening, secure the matching washer/nut, and add the knob. Keep enough clearance for the push action. Mount the joystick on its four bosses and check full travel.

4 Lid: seat the ESP32 with USB-C at the front edge. Seat the DAC on the right with its jack facing that same front edge, beside USB. Secure the optional IMU in its own cradle if fitted.

5 Reconnect the labeled harness. Insulate exposed joints, restrain wires, and keep the seam, screw bosses, antenna area and mic port clear. Check connector and pin clearance with the halves gently together.

6 With the case still open on a nonconductive surface, repeat the page 10 sound check. Unplug, align the lip, and close with four lid screws, lightly and evenly. If it resists, reopen and find the obstruction.

No wire is pinched; USB/audio plugs seat fully; the knob clicks and stick moves.

After closing, the screen, startup tone, microphone and encoder still work.

11 / MAKE YOUR FIRST BEAT
Your tiny band is ready.

Switch to JAM when the hardware checks pass. It is the case-friendly sequencer: six channels, a sampler, and a grid of musical possibilities.

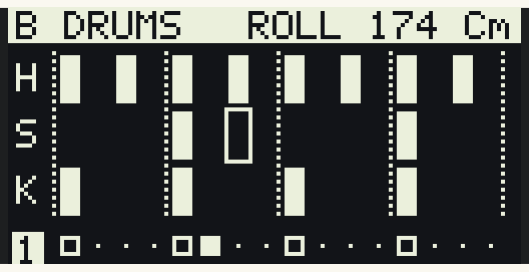
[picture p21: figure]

Actual JAM drum-grid render from the repository. The grid contains two bars of 16 steps.

Flash kit-jam.bin from the release the same way as the test image, or from source: tools/app.sh jam in the repository, then idf.py flash in firmware/. JAM is the default application when building from a fresh checkout.

esptool.py --chip esp32s3 write_flash 0x0 kit-jam.bin

Gesture in JAM | What happens
Turn encoder / flick joystick | Move the pattern cursor
Tap encoder | Toggle the selected grid cell
Hold encoder about 0.5 seconds | Next page: PATTERN, MIX, SONG, SETUP
Push encoder and turn | Change channel
Click joystick | Enter/cycle perform mode; behavior depends on channel
Hold encoder 3 seconds | Clear the current channel - use deliberately

THE FIRST-BEAT CHALLENGE
Select DRUMS on PATTERN. Put kicks on steps 1, 5, 9 and 13 of the first bar; add snare on 5 and 13 and hats on odd steps. Repeat in the second bar. Then switch to BASS and add three notes. Hear that? You built the band.

Verify the joystick moves the cursor and its click changes perform mode. JAM autosaves about two seconds after the last edit; wait a few extra seconds before unplugging. Try a sample next: select MIC and tap to record up to two seconds, then select SAMPLE. Live mic is audible only while MIC is selected.

My beat plays, the joystick works, and my pattern returns after a restart.

BONUS / OPTIONAL SIDE QUESTS
Add extras after the win.

These are independent extensions. The seven-part case has an IMU cradle; it has no designed mounting for the speaker, amplifier, or distance sensor.

Motion and distance for the looper

Module | Connections / expected I2C address
MPU6050 / GY-521 | 3.3 V-compatible VCC; GND; SDA -> GPIO12; SCL -> GPIO13. AD0 low for 0x68; verify board default.
VL53L0X breakout | Verified 3.3 V-compatible supply and I2C; GND; SDA -> GPIO12; SCL -> GPIO13. Address 0x29. Leave XSHUT/INT at the module's documented defaults.

These share the OLED's I2C wires. Check breakout supply requirements and pull-ups before connecting; pull-ups must go to 3V3. If none of the boards provide them, add one 4.7 kOhm pull-up from SDA to 3V3 and one from SCL to 3V3. Do not add a new pair blindly to every board.

Use tools/app.sh looper, then flash, to try motion and distance expression. The driver implements VL53L0X, not VL53L1X. An I2C scan finds presence; testing tilt/distance in the looper verifies actual behavior.

MAX98357A speaker branch: bench extension

Amplifier pin | Connection
BCLK / LRC / DIN | GPIO7 / GPIO8 / GPIO9 (shared with the DAC)
SD / GND / GAIN | GPIO11 / common GND / floating, if supported by your board
VIN | Verified regulated supply with enough current for the speaker load
Speaker + and - | A suitable 4 or 8 ohm speaker across the two outputs

SPEAKER OUTPUT IS NOT GROUND
Neither speaker terminal goes to GND or to the DAC jack. Do not load the SuperMini's small 3V3 regulator with the amp. For a separate rated amp supply, join grounds but do not tie its positive rail to USB 5V without a designed power path.

Current firmware enables the amp while the GPIO6 encoder switch is held, unless Kit firmware > Keep the speaker amp on all the time is enabled. BOOT's software button alias does not enable this hardware gate. The PCM5102A line-out is independent of that gate. Speaker power distribution and mounting need separate validation before boxing this extension.

RESCUE / EVERY BUILD HAS A PLOT TWIST
One clue at a time.

Unplug before touching wiring. Return to the hardware-test app for diagnosis; reconnect one stage at a time.

What you see or hear | Try this first
No serial device / flashing fails | Try a known data cable and direct USB port; close other serial monitors. Enter BOOT download mode (page 5). Check port permissions.
Screen dark; firmware running | Check OLED VCC/GND, then GPIO12 SDA and GPIO13 SCL. Look for 0x3C. Test app can retry 0x3D; JAM expects 0x3C.
Tone missing; screen works | Check external AUX/line input and volume. Unplug; check DAC VIN, BCK=7, LCK=8, DIN=9, SCK=GND and XSMT=H.
Tone works; mic silent | Check INMP441 VDD=3V3, SD=10, SCK=7, WS=8 and L/R tied low. Read the test diagnosis; inspect for a blocked mic port.
RIGHT slot message | Mic L/R is high. Supported by the firmware; not a fault if the level meter responds.
Intermittent / line stuck | Inspect fitted headers, shared grounds and loose jumpers. Reconnect with power off. Keep signal wiring short.
Repeated boots / BROWNOUT | Disconnect USB immediately if anything gets hot. Remove the newest module; check shorts, polarity, cable and power budget. Retry the known-good stage.
Encoder reversed / skips | Verify common=GND and A/B=4/5. Exchange A/B if reversed. For multiple steps per detent, check Kit firmware > Encoder counts per detent.
Joystick odd / no click | Reboot with stick centered. Check VRy=1, VRx=2, SW=3 and 3V3 power. Firmware rotation is intentional for the case.
Squeal / distortion | Lower listening volume; move speaker away from mic. Check input mode and mic gain. Do not use the DAC to drive passive speakers or headphones directly.
Line-out works; optional speaker silent | Check amp supply and SD=11. It is normally enabled only while GPIO6 is held; see page 14.
Works open, fails closed | Unplug and reopen. Look for a pinched wire, a loose connector, screw contact, blocked mic port, or knob pressed against the panel.

ASK FOR HELP WITH A GOOD CLUE
Share clear photos of both sides of each board, your GPIO-to-label wiring list, firmware application, and the relevant serial log. Include the exact module revision and what passed before the failure.

WORKBENCH CARD / KEEP THIS PAGE HANDY
Your pocket pin map.

Signal labels, not physical pin order. Unplug before changing connections. Firmware source of truth: firmware/main/pins.h.

ESP32 | Destination
GPIO1 / GPIO2 / GPIO3 | Joystick VRy / VRx / SW
GPIO4 / GPIO5 / GPIO6 | Encoder A / B / push switch; common and other switch contact -> GND
GPIO7 | Mic SCK + DAC BCK (+ optional amp BCLK)
GPIO8 | Mic WS + DAC LCK (+ optional amp LRC)
GPIO9 | DAC DIN (+ optional amp DIN)
GPIO10 | Mic SD
GPIO11 | Optional amp SD
GPIO12 / GPIO13 | OLED + optional sensors SDA / SCL
3V3 / GND | Verified 3.3 V modules / all module grounds
Verified USB 5V rail | VIN of verified regulator-equipped purple DAC only

THE EASY-TO-MISS CONNECTIONS
Mic L/R -> GND. DAC SCK -> GND. Purple DAC straps: FLT=L, DEMP=L, XSMT=H, FMT=L (confirm your revision). Never put 5 V on GPIO. Leave USB GPIO19/20 and other boot/strapping pins alone.

A few words decoded

GPIO: a programmable signal pin. DAC: digital sound to analog audio. I2S: digital audio bus. I2C: two-wire display/sensor bus. VIN/VCC/VDD: power labels whose voltage depends on the board. Continuity: a meter check for an electrical connection. Dry-fit: assemble without power or permanent fastening.

Sources and build notes

Prepared from the repository's firmware/main/pins.h, main.c, app_test.c, audio.c, input.c and Kconfig.projbuild, README.md, parts/minimal-kit.md and enclosure/. This guide documents the prototype; no physical assembly or electrical test was performed for this edition.

Project and firmware (https://github.com/willbearfruits/esp32-s3-supermini-kit)

Releases with ready-to-flash images (https://github.com/willbearfruits/esp32-s3-supermini-kit/releases)

esptool-js browser flasher (https://espressif.github.io/esptool-js/)

Espressif: install ESP-IDF v5.5 for ESP32-S3 (https://docs.espressif.com/projects/esp-idf/en/v5.5/esp32s3/get-started/index.html)

TI: PCM5102A line-output specification (https://www.ti.com/product/PCM5102A)

Adafruit: MAX98357A breakout pinouts (match your board) (https://learn.adafruit.com/adafruit-max98357-i2s-class-d-mono-amp/pinouts)

Illustrations are editable SVGs with PNG companions; case and JAM images come from this repository. Documentation and artwork: MIT, as in the repository license.

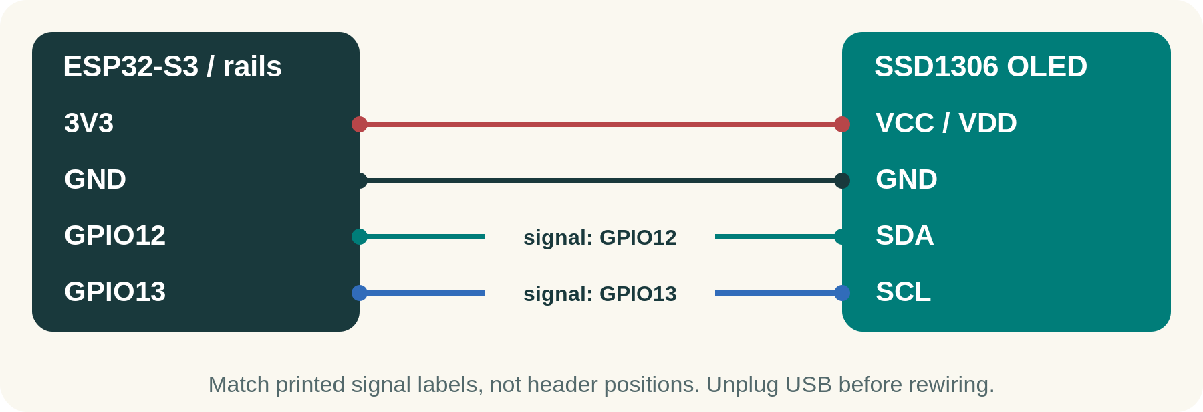
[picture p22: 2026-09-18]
docs/assembly/assets/display.png

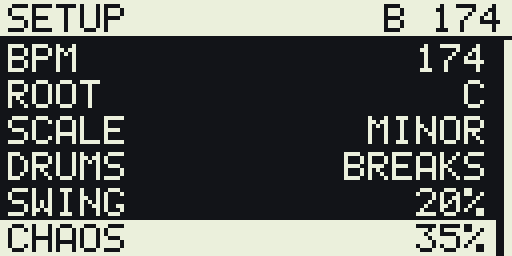
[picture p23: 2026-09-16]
images/jam/setup.png

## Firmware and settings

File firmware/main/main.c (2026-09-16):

// Common bring-up: self-test, GPIO, I2C scan, OLED, audio engine. Then hands
// over to the application chosen in menuconfig (Kit firmware -> Application):
// the voice looper or the multi-mode voice instrument.
#include <stdio.h>
#include "freertos/FreeRTOS.h"
#include "freertos/task.h"
#include "driver/gpio.h"
#include "driver/i2c_master.h"
#include "esp_log.h"
#include "esp_rom_sys.h"
#include "sdkconfig.h"

#include "pins.h"
#include "oled.h"
#include "audio.h"
#include "fx.h"
#include "selftest.h"
#include "song.h"
#include "app.h"

static const char *TAG = "kit";
#define OLED_ADDR 0x3C

static void gpio_setup(void)
{
    gpio_config_t amp = { .pin_bit_mask = 1ULL << PIN_AMP_SD, .mode = GPIO_MODE_OUTPUT };
    ESP_ERROR_CHECK(gpio_config(&amp));
    gpio_set_level(PIN_AMP_SD, 0);

    gpio_config_t in = { .pin_bit_mask = 1ULL << PIN_ENC_SW, .mode = GPIO_MODE_INPUT, .pull_up_en = GPIO_PULLUP_ENABLE };
    ESP_ERROR_CHECK(gpio_config(&in));
}

// A reset in the middle of an I2C transfer can leave a slave holding SDA
// low, and then nothing answers. Clock SCL until it lets go, then a STOP.
static void i2c_recover(void)
{
    gpio_config_t io = { .pin_bit_mask = (1ULL << PIN_I2C_SDA) | (1ULL << PIN_I2C_SCL),
                         .mode = GPIO_MODE_INPUT_OUTPUT_OD, .pull_up_en = GPIO_PULLUP_ENABLE };
    gpio_config(&io);
    gpio_set_level(PIN_I2C_SDA, 1); gpio_set_level(PIN_I2C_SCL, 1);
    esp_rom_delay_us(20);
    if (gpio_get_level(PIN_I2C_SDA) == 0) {
        ESP_LOGW(TAG, "I2C SDA held low, recovering");
        for (int i = 0; i < 16 && gpio_get_level(PIN_I2C_SDA) == 0; i++) {
            gpio_set_level(PIN_I2C_SCL, 0); esp_rom_delay_us(10);
            gpio_set_level(PIN_I2C_SCL, 1); esp_rom_delay_us(10);
        }
        gpio_set_level(PIN_I2C_SDA, 0); esp_rom_delay_us(10);      // STOP
        gpio_set_level(PIN_I2C_SCL, 1); esp_rom_delay_us(10);
        gpio_set_level(PIN_I2C_SDA, 1); esp_rom_delay_us(10);
    }
    gpio_reset_pin(PIN_I2C_SDA); gpio_reset_pin(PIN_I2C_SCL);
}

static i2c_master_bus_handle_t i2c_setup(void)
{
    i2c_recover();
    i2c_master_bus_handle_t bus = NULL;
    i2c_master_bus_config_t cfg = {
        .clk_source = I2C_CLK_SRC_DEFAULT,
        .i2c_port = I2C_NUM_0,
        .sda_io_num = PIN_I2C_SDA,
        .scl_io_num = PIN_I2C_SCL,
        .glitch_ignore_cnt = 7,
        .flags.enable_internal_pullup = true,
    };
    ESP_ERROR_CHECK(i2c_new_master_bus(&cfg, &bus));
    for (uint8_t a = 0x08; a <= 0x77; a++) {
        if (i2c_master_probe(bus, a, 20) == ESP_OK) ESP_LOGI(TAG, "I2C device at 0x%02X", a);
    }
    return bus;
}

void app_main(void)
{
    vTaskDelay(pdMS_TO_TICKS(300));
#if defined(CONFIG_KIT_APP_LOOPER)
    ESP_LOGI(TAG, "kit voice looper, %d Hz", CONFIG_KIT_SAMPLE_RATE);
#elif defined(CONFIG_KIT_APP_TEST) || defined(CONFIG_KIT_APP_FAUST)
    ESP_LOGI(TAG, "kit hardware test, %d modes, %d Hz", fx_count, CONFIG_KIT_SAMPLE_RATE);
#elif defined(CONFIG_KIT_APP_JAM)
    ESP_LOGI(TAG, "kit JAM, %d Hz", CONFIG_KIT_SAMPLE_RATE);
#else
    ESP_LOGI(TAG, "kit voice instrument, %d modes, %d Hz", fx_count, CONFIG_KIT_SAMPLE_RATE);
#endif

    selftest_pins();
    gpio_setup();

    i2c_master_bus_handle_t bus = i2c_setup();
    if (oled_init(bus, OLED_ADDR) == ESP_OK) ESP_LOGI(TAG, "OLED up");
    else ESP_LOGW(TAG, "no OLED, continuing without display");

#ifdef CONFIG_KIT_APP_LOOPER
    song_init();
#endif
    audio_start();

#if defined(CONFIG_KIT_APP_LOOPER)
    app_looper_run(bus);
#elif defined(CONFIG_KIT_APP_TEST) || defined(CONFIG_KIT_APP_FAUST)
    app_test_run(bus);
#elif defined(CONFIG_KIT_APP_JAM)
    app_jam_run(bus);
#else
    app_instrument_run();
#endif
}

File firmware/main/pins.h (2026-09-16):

// Pin map for the ESP32-S3 SuperMini kit.
// Keep this in sync with docs/pinmap.md.
#pragma once

// --- Joystick (analog, must stay on ADC1 = GPIO1..GPIO10, ADC2 dies with WiFi)
#define PIN_JOY_X     2
#define PIN_JOY_Y     1
#define PIN_JOY_SW    3   // active low, internal pull-up

// --- Rotary encoder
#define PIN_ENC_A     4
#define PIN_ENC_B     5
#define PIN_ENC_SW    6   // active low, internal pull-up

// --- I2S, one port in full duplex. Clocks shared by mic and both DACs.
#define PIN_I2S_BCLK  7   // -> INMP441 SCK, PCM5102A BCK, MAX98357A BCLK
#define PIN_I2S_WS    8   // -> INMP441 WS,  PCM5102A LCK, MAX98357A LRC
#define PIN_I2S_DOUT  9   // -> PCM5102A DIN, MAX98357A DIN. PCM5102A SCK must go to GND and its XSMT bridge to H, or it is silent.
#define PIN_I2S_DIN   10  // <- INMP441 SD

// --- Speaker amp control
#define PIN_AMP_SD    11  // MAX98357A SD_MODE: low = shutdown, high = (L+R)/2

// --- I2C bus: OLED (0x3C), ToF (0x29), IMU (0x68)
#define PIN_I2C_SDA   12
#define PIN_I2C_SCL   13

// --- Spare
#define PIN_SPARE     21  // ToF XSHUT or IMU INT later

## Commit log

2026-09-06 Milestone 0: pin map and I2S mic-to-DAC loopback firmware
    ESP32-S3 SuperMini kit. One I2S port in full duplex feeds an INMP441 mic
    into a PCM5102A and MAX98357A that share the bus. Includes pin map docs,
    ESP-IDF project, MIT license.
    Claude-Session: https://claude.ai/code/session_01XKGHMTXXQ89Laye7X1L6j2
2026-09-06 Milestone 1: hardware test firmware, mic + DAC + OLED verified
    Replace the loopback app with kit_hwtest, which brings up and checks every
    wired module at boot and keeps running as a live monitor:
    - I2C scan and SSD1306 OLED via esp_lcd, with a small framebuffer driver
    and 5x7 font (oled.c, font5x7.h)
    - pin-to-pin short test and a pull test on the mic data line
    - read-back self-test proving BCLK/WS/DOUT are toggling
    - scan of spare GPIOs for a misplaced data wire
    - 440 Hz tone on the DACs, then mic loopback with a level meter and
    waveform on the OLED; the tone returns whenever the mic drops out
    The INMP441 leaves junk in the low 8 bits of each 32-bit word, so samples
    are masked to 24 bi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
    [main.c, oled.c, pins.h]
2026-09-06 Milestone 2: voice instrument firmware with eight modes
    Replace the hardware test with kit_instrument. Sing or talk into the mic
    and the active mode turns it into sound on the DACs; the BOOT button steps
    through modes; the OLED shows mode, detected note, output meter and
    waveform.
    - audio.c: I2S full duplex engine, float pipeline, soft-clip output
    - voice.c: level gate with adaptive noise floor, YIN pitch tracking,
    semitone quantisation with hysteresis
    - modes: vocoder, autotune, guitar lead, guitar chords (Karplus-Strong
    strings through distortion), delay, reverb, rhythmic stutter, mic test
    - selftest.c keeps the boot-time short and pull tests from milestone 1
    - usb_midi.c: TinyUSB MID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
    [audio.c]
2026-09-06 Milestone 3: voice looper app (drums, bass, chords, lead, vocal)
    One-button looper built on the same audio engine. The first beatbox take
    sets loop length and tempo, bass locks the key, chords/lead quantise to the
    grid and scale, vocal page is a hard hyperpop autotune recorded as mu-law
    audio. Chosen at build time via Kconfig (KIT_APP_LOOPER, default) with the
    eight-mode instrument kept as KIT_APP_INSTRUMENT.
    Claude-Session: https://claude.ai/code/session_016akWv89w2Thjpn1MhyjShu
2026-09-06 Engine rework: 32 kHz, PSRAM, per-sample control, tracker and tempo fixes
    - Enable the S3's embedded 2 MB PSRAM; the vocal loop lives there.
    - 32 kHz, 64-frame blocks, 3-deep DMA queue (~6 ms round trip).
    - TPT state variable filter with per-sample cutoff, polynomial tan/sin,
    no libm in per-sample loops, hot loops in IRAM, -O3 -ffast-math.
    - Cycle-counter CPU meter on the OLED and in the log.
    - Voice tracker: start-up noise calibration, median pitch, settle/drift
    note model, onset age for latency compensation.
    - Looper: onset threshold above the noise floor, hits fit the tempo,
    loop anchored on the first hit, lag-compensated quantisation.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
    [audio.c]
2026-09-07 3D: parametric OpenSCAD bodies (slab, ocarina, cup) and acoustics notes
    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
    [acoustics.scad, cup.scad, handheld.scad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]
2026-09-07 Looper product pass: controls, mixer, kits, autosave, export, USB mode, new UI
    - Mixer: per-layer volume/mute/reverb/delay sends, kick sidechain pump,
    2x oversampled clipper, lookahead limiter (anti-denormal, no libm).
    - Drum kits (TIGHT, 808, LOFI) plus a user sample kit from storage.
    - Overdub by default, undo, replace-next, swing, humanise, any layer first.
    - Inputs: encoder (PCNT), joystick (ADC, auto-detected), BOOT alias,
    MPU6050 tilt and VL53L0X hand distance as expression.
    - Storage: NVS autosave of the song, vocal loop on a wear-levelled FAT
    partition, WAV stems + MIDI + notes export by real-time bounce.
    - USB mode (menu or encoder held at boot): mass storage + MIDI device.
    -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
    [partitions.csv]
2026-09-07 Looper: tracks, scenes, arrangement, stereo mix, presets, song slots
    - Up to 8 tracks of five kinds (drums, bass, keys, lead, vocal), add or
    delete tracks, start with any of them; 4 patterns per track selected by
    scene, empty patterns fall back to A; arrangement of scenes with song
    mode; queued scene switches from the joystick.
    - Stereo mixer: pan, low cut, tilt tone, reverb and ping-pong delay sends,
    solo, sidechain per track, master tone/drive/limiter.
    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
2026-09-07 Looper: fix dropped downbeat, autosave clicks, bass and sounds, per-track effects
    - Takes now keep hits and notes played just before the count-in ends or
    just after the take ends (they belong to step 0); a note held across
    the loop start gets its attack. Overdubs play the existing pattern
    while recording, skipping steps written in this take. Beatbox
    classification window 16 -> 8 ms.
    - Flash auto-suspend so autosave no longer stalls the audio core; track
    changes only save after 10 s of quiet, never while armed or recording.
    - Bass reworked (sine sub default), synth gets sine/tri waves and phase
    modulation, five presets per kind, TRAP drum kit, pitch stability
    setting, per-track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
2026-09-08 docs: restore GPIO 7/8 rows in the pin map, add wiring diagram
    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
2026-09-08 docs: PCM5102A VIN from 5V
    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
2026-09-08 Hardware test app: 440 Hz sine with a -50..0 dB level sweep; tools/app.sh to switch apps
    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
2026-09-08 Hardware test app: OLED pages and hot-plug I2C rescan
    Claude-Session: https://claude.ai/code/session_018SpnxhrqRLbH7f9jFhNzBD
2026-09-08 Test app: mic page and passthrough, OLED 180-degree option, I2C bus recovery at boot
    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
2026-09-08 Test app: mic-only passthrough with raw I2S diagnostics, SD/clock probes, encoder page
    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
2026-09-08 Test app: stuck-mic detection with I2S restart and SD probe, time-based clock check
    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
    [app_test.c, audio.c]
2026-09-08 Test app: shorted-pin check on the I2S clocks when the mic sticks
    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
    [app_test.c, audio.c]
2026-09-09 Test app: mic and screen only, boot reason and counter on screen, weak-only pin test
    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
2026-09-14 CLAUDE.md: hardware test app, app switcher, enclosure and parts folders
    Add the enclosure (OpenSCAD case with renders and STLs), the parts
    purchasing research and the board photo, and point the README at the
    minimal purchasing list.
    Claude-Session: https://claude.ai/code/session_01Vo1HA1oztHARfAsxy64Ea9
    [Waveshare-ESP32-S3-Zero-v2.stp, bom.csv, enclosure.scad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]
2026-09-16 Firmware: mic slot auto-detect, test app effects with presets, Faust showcase app
    audio.c finds which I2S slot the INMP441 drives (L/R pin high or low) and
    uses it. The test app gets delay, reverb and beat repeat with presets, a
    boot-time DAC tone, and BOOT tap/hold to change effect/preset through a new
    optional preset hook in fx_t. New KIT_APP_FAUST application: seven Faust
    programs (zita reverb, pitch shift, wah, amp sim, flanger, compressor,
    mic-following synth) compiled by tools/faustgen.sh into C++ classes and
    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
2026-09-16 Enclosure: parametric PCM5102A board, 32 x 17 mm, jack out the front wall
    Board size, jack edge and offset, wall and cradle fit are a Customizer group
    in enclosure.scad; parts.scad draws in the board's own frame. Renders and
    STLs regenerated.
    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
    [enclosure.scad, lid.stl, parts.scad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]
2026-09-16 JAM app: scale-locked step sequencer with sampler scratch, mixer and joystick
    New KIT_APP_JAM: six channels (drums, bass, lead, pad, sample, mic) on a
    32-step grid edited with encoder and joystick; melodic rows are degrees of
    a selectable scale, pad rows are chord degrees. Bass and lead are a Faust
    Moog voice (faust/jam_voice.dsp via faust_voice.cpp), pad is synth.c,
    drums kit.c, master mix.c with a new no-oversampling option. Sampler
    records from the mic channel and scratches with the joystick in perform
    mode. Pages: PATTERN, MIX, SETUP.
    Joystick: channels now come from pins.h (VRy GPIO1, VRx GPIO2), ADC reads
    averaged, detection tolerates a jittery stick. voice_set_pitch() lets an
    app ski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
    [app_jam.c, input.c]
2026-09-16 JAM: drum styles load into the grid, encoder-only navigation, joystick rotation
    Boot silent; picking a style in SETUP copies it into the editable drum grid.
    BOOT is unreachable in the case, so encoder hold = page, push+turn =
    channel, 3 s = clear channel, CLEAR ALL in SETUP. Joystick axes rotated a
    quarter turn to match the mounting.
    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
    [app_jam.c, input.c]
2026-09-16 JAM: autosave to /storage/jam, sample slice mode with reverse, ratchet roll
    State and the recorded sample persist across power cycles (state.bin +
    sample.raw, saved 2 s after the last edit and after each recording). The
    sample channel can run in SLICE mode: 8 slice rows, cells cycle
    forward/reverse/off. Joystick click cycles perform modes; ROLL retriggers
    the last hit on DRUMS or SAMPLE at 1/8..1/64 from the X tilt with a level
    or pitch ramp from Y.
    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
    [app_jam.c]
2026-09-16 JAM: chaos step mutations, mixer insert effects, tempo to 250
    CHAOS in SETUP gives each drum or sample step that chance of a mutation:
    short automatic roll, dropped hit, swapped drum, another slice, reversed
    slice or an octave jump. The MIX page exposes mix.c's insert effects
    (drive, crush, chorus, phaser, wobble, tremolo) and their amount per
    channel. State file version 3.
    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
    [app_jam.c]
2026-09-16 JAM: four pattern banks with instant switching and copy
    Drum grid and note lanes live in banks A-D. Encoder held + joystick flick
    up/down switches banks instantly, keeping the playhead; SETUP has PATTERN
    and COPY (current bank to the next, then switch). State file version 4.
    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
    [app_jam.c]
2026-09-16 JAM: song arrangement, eight banks, new UI look
    SONG page chains banks (16 slots, bank x repeats, play from any slot,
    loops at the end marker). Banks A-H. Every page redrawn: inverted title
    bar, drum-machine step lights and beat lines on the grid, channel-strip
    mixer with vertical faders, aligned settings list with scrollbar, song as
    a timeline of blocks. State file version 5.
    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
    [app_jam.c]
2026-09-16 JAM UI: mixer fx letter beside the name, song help line fits; page renders in images/jam
    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
    [app_jam.c]
2026-09-18 Assembly guide: flash from release images, links to it from README and case docs
    The guide's flashing steps now lead with the release .bin files and esptool,
    with ESP-IDF as the alternative; reference page links to releases and the
    browser flasher. Regenerated Markdown, HTML and PDF from guide.json; the PDF
    is committed under output/pdf so the links resolve.
    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
